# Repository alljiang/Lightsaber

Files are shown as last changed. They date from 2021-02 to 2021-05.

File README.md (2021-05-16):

# Lightsaber

EE445L Embedded Systems Lab with Dr. Valvano <br />
Final Project, 1st place in class design competition <br />
Spring 2021 <br />
Team Members: Allen Jiang, Sophia Jiang, Adeel Rehman, Sharon Chen <br />
<br />
<b>Features:</b> <br />
* Circuit Board
  * Compact 4-Layer design (Board dimensions: 1.94" x 0.90")
  * TM4C Microcontroller
  * 12-bit DAC and audio amplifier output
  * MPU-6500 IMU
  * ESP-01S Wifi Module
  * Power initiated by button and latched on by MCU - allows for zero vampire power
  * USB-C Battery Charging
  * Onboard battery protection (overvoltage, undervoltage, short)
* Firmware
  * Neopixels driven by Ping-Pong uDMA
  * ESP-01S AP-mode for TCP-IP communication with Android app
  * Android app for on-the-fly color, blade effect, and audio configuration with voltage and temperature telemetry
  * Smoothswing v2 algorithm implementation
* Hardware
  * Hilt
    * Designed in Fusion 360
    * 1" aluminum core hilt
    * Holes drilled and tapped for button access, charging port access, and mounting 3D printed parts
    * Grooves cut using a milling bit on a drill press
    * 3D printed cosmetic attachments are finished through sanding, filler spray coat, and final spray paint coat
  * Blade
    * Polycarbonate tubing (1" OD, 0.125" walls)
    * 2 parallel back-to-back LED strips of 144 pixels/m WS2812B neopixels - up to 15 amps of current
    * LEDs diffused using layers of foam and cellophane. Polycarbonate tubing is sanded on the outside.
    * 3D printed blade cap using translucent filament
  * Blade connector
    * Custom designed as two 1" circular 4-layer PCBs
    * No latching components - easy and quick connect/disconnect
    * Hilt-side connector uses 19 pogo pins to contact with 3 large ring pads on blade-side connector
  * Chassis
    * Holds electronic internals together for durability and convenience
    * 3D printed PLA
    * Houses RGB button, PCB, 21700 Li-ion battery, speaker, and hilt-side blade connector
    * Blade connector mounted using screws and hot-melt insert
    * RGB button connected with ribbon cable
<br />
  <b>Video Link:</b>
<br />

(https://www.youtube.com/watch?v=Yrs18WD5HyQ)

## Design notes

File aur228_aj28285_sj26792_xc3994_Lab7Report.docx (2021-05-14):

EE 445L Lab 7 Report Deliverables

Team members: aur228, aj28285, sj26792, xc3994

Requirements Document: Lightsaber

1. Overview
  1.1. Objectives

The objectives of this project are to design, build, and test a custom embedded system. In practice, we are building a lightsaber. Our goal is to demonstrate our understanding of embedded systems design.

  1.2. Roles and Responsibilities

We are both the engineers and the clients because we are both making a lightsaber and want a lightsaber. Responsibilities will be divided based on accessibility to lab equipment and prior PCB design experience.

  1.3. Interactions with Existing Systems

Our system will interact with a NeoPixel LED strip to output lighting effects.

2. Function Description
  2.1. Functionality

We will attempt to closely resemble the functionality of a “real” lightsaber. There will be a handle for the user to grasp, and an illuminated endpiece. If the user presses the button, the lightsaber will turn on and off. Using the lightsaber’s wi-fi connection, the user will be able to configure lightsaber settings using an app, such as color and sound. Sound and lighting effects will play depending on the lightsaber’s movement.

  2.2. Performance

The system will be judged first by the Spring 2021 EE 445L class, at the end of year competition. Second, it will also be judged by our satisfaction of the project.

Other criteria include software organization and readability, the system’s response to stimuli, and ease-of-use.

  2.3. Usability

The system will be easy to use, and not require any training. There will be very few buttons on the side of the lightsaber to control lighting. Most features will use sensor data to trigger.

3. Deliverables
  3.1. Reports

The reports for Labs 7 and 11 will be written.

  3.2. Outcomes

For Lab 7, we will deliver this requirements document, a schematic of our PCB, our software, current and cost estimations, and a discussion on debugging our system.

For Lab 11, we will deliver a more detailed requirements document, a detailed PCB schematic, a ½ page report on our software architecture, and measurement data for our system.

Additionally, we will deliver a YouTube video showcasing our product.

PCB and Schematics: uploaded on GitHub

Discussion: Debugging plan

HARDWARE:

(PCB and circuit already built and soldered, everything appears to be working correctly so far)

- We have access to lab equipment including an oscilloscope, microscope, soldering equipment, and multimeters.
- Individual connections and expected voltages can be tested using the oscilloscope, multimeter, or microscope if needed.

SOFTWARE:

- JTAG connector to enable remote testing on the board.
- Lightsaber functionalities split into different modules, which will be unit tested separately before integration
- Each member will be responsible for a few modules and the team will work together to understand other modules and how they combine.
- Modules needed include (but aren’t limited to) Buttons, timers, JTAG, WIFI (ESP module), NeoPixel LED drivers, ect.
- Modules will be integrated in tiers. Associated components will be integrated together in larger modules and tested before implementing the larger modules fully in the main loop.
- During testing stage, we will use a prototype main loop with a debugging driver to run only the things we want to test.

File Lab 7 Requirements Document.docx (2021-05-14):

EE 445L Lab 11 Report Deliverables

Requirements Document: Lightsaber

1. Overview
  1.1. Objectives

The objectives of this project are to design, build, and test a custom embedded system. In practice, we are building a lightsaber, modeled from the movie Star Wars. The lightsaber should contain lighting and sound effects which are played in response to stimuli. Our goal is to demonstrate our understanding of embedded systems design, and showcase our knowledge gained in EE 445L.

  1.2. Process

The project will be developed using the TM4C microprocessor. A custom PCB will be designed, and the microcontroller and other electrical components soldered to it. A JTAG header will be used to program and debug the embedded system. A battery and charging circuit will be soldered to provide power to the device. The user will use a custom Android app to control the sound and lighting effects of the device. There will be numerous software and hardware modules, all of which will be independently tested and validated. After each module is tested, the system will be built and tested.

  1.3. Roles and Responsibilities

We are both the engineers and the clients because we are both making a lightsaber and want a lightsaber. Responsibilities will be divided based on accessibility to lab equipment and prior PCB design experience.

  1.4. Interactions with Existing Systems

Our system will interact with a NeoPixel LED strip to output lighting effects. The NeoPixel’s interface with the TM4C using direct memory access.

Our system will also interact with our custom Android application through an ESP-01 Wi-Fi module. The user will be able to use this app to select color and sound effects to be loaded onto the embedded system. The Blynk app and interface covered in class will not be used. We will instead be using the standard AT command set that ships with the ESP module to interface with it. App communication will be done using a custom TCP protocol developed by us.

2. Function Description
  2.1. Functionality

We will attempt to closely resemble the functionality of a “real” lightsaber. There will be a handle for the user to grasp, and an illuminated endpiece. If the user presses the button, the lightsaber will turn on and off. Using the lightsaber’s wi-fi connection, the user will be able to configure lightsaber settings using an app, such as color and sound. Color can be selected from the Adobe RGB color space. Sound can be selected from a pre-loaded library in the firmware. Sound and lighting effects will play depending on the lightsaber’s movement.

There will be 8 different blade effects, 2 unique sound fonts, and a special nyan cat package.

  2.2. Performance

We will be using three primary qualitative measures to assess the performance of the system. The system will be judged first by the Spring 2021 EE 445L class, at the end of year competition. Second, it will also be judged by our satisfaction of the project. Third, it will be judged by its ability to impress our course instructor and faculty advisor, Dr. Valvano.

Other secondary criteria include software organization and readability, the system’s response to stimuli, and ease-of-use.

The software will be organized in a readable, and sharable manner. Software reviewers will be able to understand the software architecture without needing a call graph. All code will adhere to the Power Up Coding Standard for C and C++.

The system will primarily respond to IMU input. The latency must be sufficiently low that the user is not able to observe it without specialized equipment.

  2.3. Usability

The system will be easy to use, and not require any special training. There will be a single button on the side of the lightsaber toggle the system on and off. The user will download an app onto their phone from the Google play store, which can be used to control the systems sound and lighting effects. Sound effects can be chosen from a list of pre-established choices. Lighting can be chosen from the Adobe RGB color scheme, featuring 16.8 million unique colors. All other features will use input from the IMU to trigger, and not require any specific user input.

3. Deliverables
  3.1. Objectives

This 2-page requirements document.

  3.2. Hardware Design

A detailed circuit diagram of the system will be uploaded to an official github repository, to be shared with the course instructor.

  3.3. Software Design

A brief description of how our software works will be delivered.

All our software will be uploaded to an official github repository, to be shared with the course instructor and teaching assistants.

  3.4. Measurement Data

Measurement data will be included as appropriate for our system. Data will describe power consumption of system and LED’s. We will also measure the duration of the Wi-Fi handler, and the smooth swing accuracy.

  3.5. Analysis and Discussion

We will not be delivering any analysis or discussion regarding our system. A YouTube video featuring our product will be submitted to the course instructor and teaching assistants as requested.

Software Design:

Individual drivers have been built for numerous low-level hardware components, including the System Timer, NeoPixel LED’s, IMU, ESP-01, the button, sound, and battery charging.

On top of these drivers, are more complex function libraries, such as WiFi and Utilities.

All the above-mentioned modules are integrated in a main file. This file handles the primary control loop and manages initialization and updates for the other modules.

Measurement Data:

Power Measurements:

Average current drawn by total PCB: ~80mA

Current drawn by neopixels: Up to 15A

Timing Measurements:

Wifi Handler Duration: 8ms

Smoothswing accuracy:

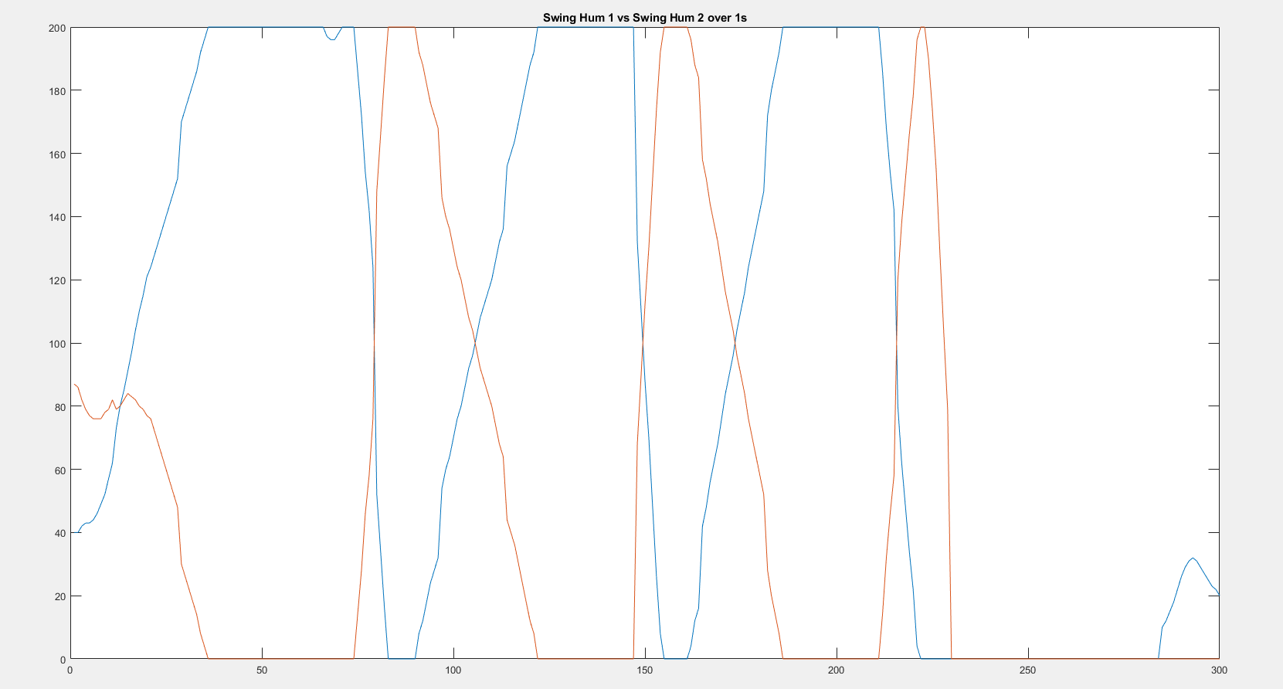
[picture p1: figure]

IMU gyro error when not moving: ~0.9 dps

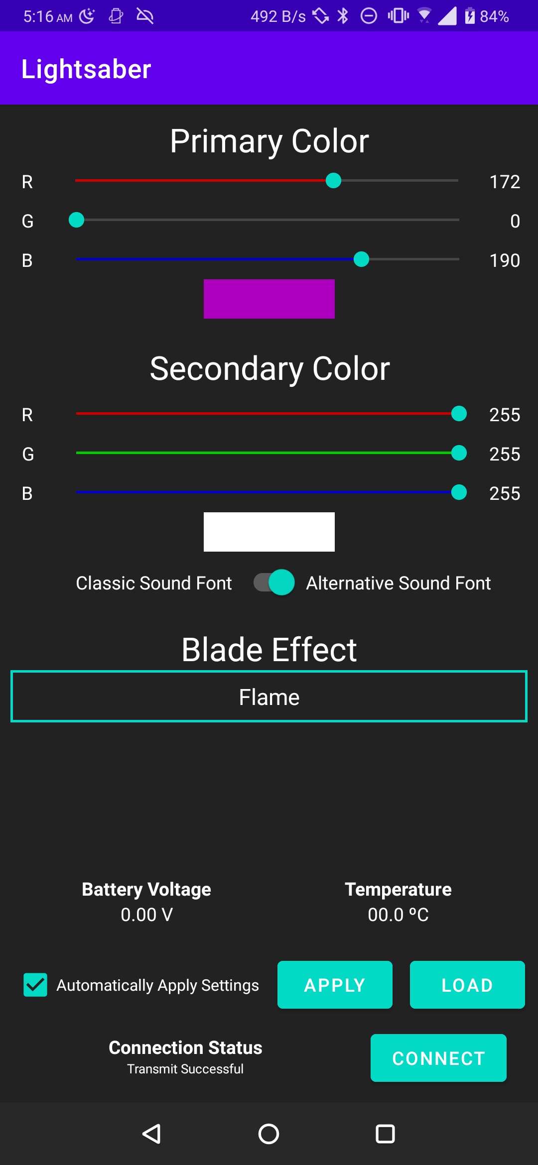
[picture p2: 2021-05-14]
Android App/screenshot2.jpg

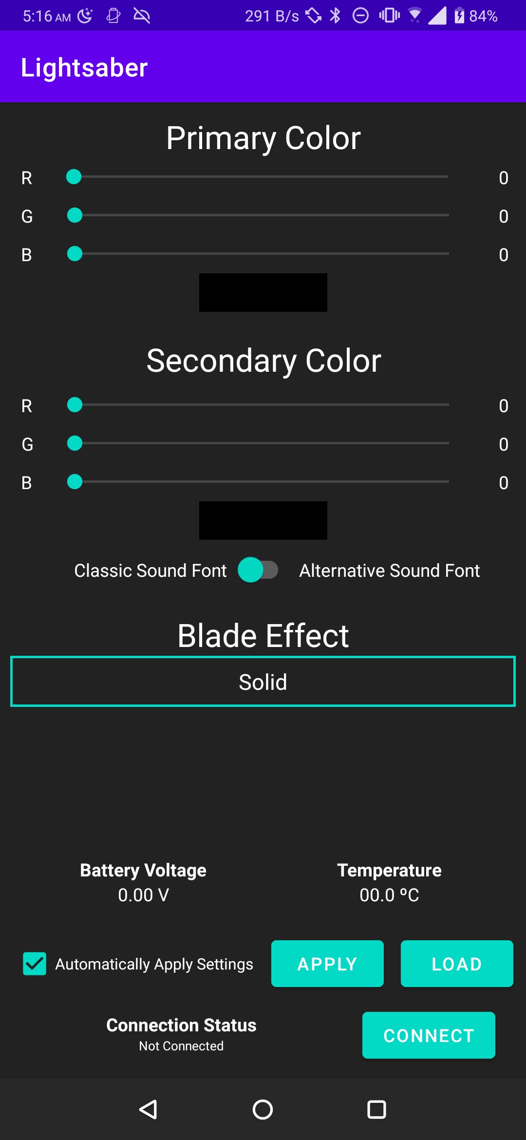
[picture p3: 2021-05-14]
Android App/screenshot1.jpg

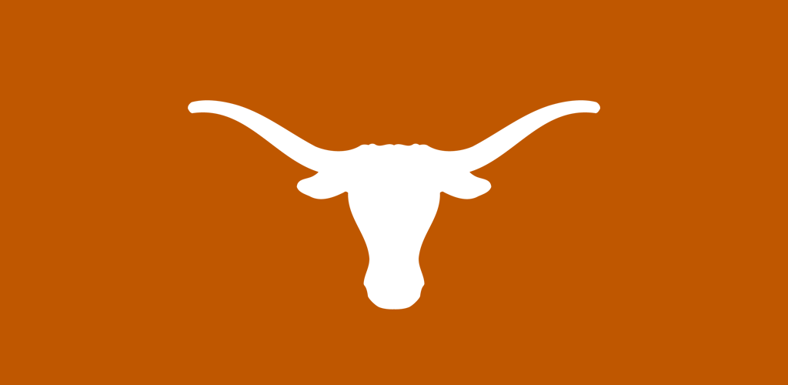
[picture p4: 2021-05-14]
Android App/feature graphic.png

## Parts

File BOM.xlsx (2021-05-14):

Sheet: Overview
Subsystem | True Cost | BOM Cost | Total Spent | Allowance | $60.00
Blade | $27.82 | $18.92 | $160.06 | Total Cost | $41.09
Hilt Electronics | $31.46 | $15.61 | $280.10 | Remaining | $18.91 | Summary:
Hilt Chassis | $8.07 | $6.56 | $95.44 |  |  | 445L BOM Cost | $41.09
 |  |  |  |  |  | Unit Cost | $67.35
 |  |  |  |  |  | Total Spent | $535.60

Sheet: Blade
Name | Description | True PPU | True Units | BOM PPU | BOM Units | True Total | BOM Total | Vendor |  |  | Purchased
Spring Pins | Contacts between blade PCB and hilt PCB, 1 data, 9 postive, 9 gnd | $12.18 | 0.13 | $0.08 | 19.00 | $1.54 | $1.54 | LCSC (https://lcsc.com/product-detail/Electronic-Accessories_Shenzhen-Kinghelm-Elec-KH-204065-DZ_C530676.html) |  |  | 150
Blade-Side PCB | Panelized | $0.00 | 1.00 | $0.00 | 1.00 | $0.00 | $0.00 | JLCPCB | True Total: | $27.82
Hilt-Side PCB | Panelized | $0.00 | 1.00 | $0.00 | 1.00 | $0.00 | $0.00 | JLCPCB | BOM Total: | $18.92
Blade-Side PCB Holder | 3D Printed | $0.00 | 1.00 | $0.00 | 1.00 | $0.00 | $0.00 | -
Hilt-Side PCB Holder | 3D Printed | $0.00 | 1.00 | $0.00 | 1.00 | $0.00 | $0.00 | - | Total Spent: | $160.06
Polycarbonate Tubing | 1" OD, 3/4" ID, Clear polycarbonate, 72" | $52.35 | 0.17 | $13.53 | 0.44 | $8.72 | $6.01 | Amazon
Cellophane | Clear Cellophane for diffusion, 32" x 100' | $7.57 | 0.33 | $7.57 | 0.33 | $2.52 | $2.52 | Amazon (https://www.amazon.com/Cellophane-Inches-Baskets-Flowers-Unfolds/dp/B07WK8PPNH)
Foam Roll | 12" wide, 50 ft, 1/16" thickness, perforated | $11.75 | 0.10 | $11.75 | 0.06 | $1.18 | $0.70 | eBay (https://www.ebay.com/itm/UBOXES-Foam-Wrap-Roll-12-Wide-x-50-ft-1-16-Thickness-Perforated-Every-12/224097161092)
Tube Cap | 3D Printed | $0.00 | 1.00 | $0.00 | 1.00 | $0.00 | $0.00 | -
Neopixel Strip | 144 Pixels per meter, 1 meters, $4 off coupon | $76.21 | 0.18 | $5.00 | 1.63 | $13.86 | $8.14 | Aliexpress (https://www.aliexpress.com/item/32838802305.html?spm=a2g0s.9042311.0.0.16ae4c4dBNLXll)
 |  | $0.00 |  | $0.00 |  | $0.00 | $0.00
 |  | $0.00 |  | $0.00 |  | $0.00 | $0.00
 |  | $0.00 |  | $0.00 |  | $0.00 | $0.00
 |  | $0.00 |  | $0.00 |  | $0.00 | $0.00
 |  | $0.00 |  | $0.00 |  | $0.00 | $0.00
 |  | $0.00 |  | $0.00 |  | $0.00 | $0.00
 |  | $0.00 |  | $0.00 |  | $0.00 | $0.00
 |  | $0.00 |  | $0.00 |  | $0.00 | $0.00
 |  | $0.00 |  | $0.00 |  | $0.00 | $0.00
 |  | $0.00 |  | $0.00 |  | $0.00 | $0.00
 |  | $0.00 |  | $0.00 |  | $0.00 | $0.00
 |  | $0.00 |  | $0.00 |  | $0.00 | $0.00
 |  | $0.00 |  | $0.00 |  | $0.00 | $0.00
 |  | $0.00 |  | $0.00 |  | $0.00 | $0.00
 |  | $0.00 |  | $0.00 |  | $0.00 | $0.00
 |  | $0.00 |  | $0.00 |  | $0.00 | $0.00
 |  | $0.00 |  | $0.00 |  | $0.00 | $0.00
 |  | $0.00 |  | $0.00 |  | $0.00 | $0.00
 |  | $0.00 |  | $0.00 |  | $0.00 | $0.00
 |  | $0.00 |  | $0.00 |  | $0.00 | $0.00
 |  | $0.00 |  | $0.00 |  | $0.00 | $0.00
 |  | $0.00 |  | $0.00 |  | $0.00 | $0.00
 |  | $0.00 |  | $0.00 |  | $0.00 | $0.00
 |  | $0.00 |  | $0.00 |  | $0.00 | $0.00
 |  | $0.00 |  | $0.00 |  | $0.00 | $0.00
 |  | $0.00 |  | $0.00 |  | $0.00 | $0.00
 |  | $0.00 |  | $0.00 |  | $0.00 | $0.00
 |  | $0.00 |  | $0.00 |  | $0.00 | $0.00
 |  | $0.00 |  | $0.00 |  | $0.00 | $0.00
 |  | $0.00 |  | $0.00 |  | $0.00 | $0.00
 |  | $0.00 |  | $0.00 |  | $0.00 | $0.00
 |  | $0.00 |  | $0.00 |  | $0.00 | $0.00
 |  | $0.00 |  | $0.00 |  | $0.00 | $0.00
 |  | $0.00 |  | $0.00 |  | $0.00 | $0.00
 |  | $0.00 |  | $0.00 |  | $0.00 | $0.00
 |  | $0.00 |  | $0.00 |  | $0.00 | $0.00
 |  | $0.00 |  | $0.00 |  | $0.00 | $0.00
 |  | $0.00 |  | $0.00 |  | $0.00 | $0.00
 |  | $0.00 |  | $0.00 |  | $0.00 | $0.00
 |  | $0.00 |  | $0.00 |  | $0.00 | $0.00
 |  | $0.00 |  | $0.00 |  | $0.00 | $0.00
 |  | $0.00 |  | $0.00 |  | $0.00 | $0.00
 |  | $0.00 |  | $0.00 |  | $0.00 | $0.00
 |  | $0.00 |  | $0.00 |  | $0.00 | $0.00
 |  | $0.00 |  | $0.00 |  | $0.00 | $0.00
 |  | $0.00 |  | $0.00 |  | $0.00 | $0.00
 |  | $0.00 |  | $0.00 |  | $0.00 | $0.00
 |  | $0.00 |  | $0.00 |  | $0.00 | $0.00
 |  | $0.00 |  | $0.00 |  | $0.00 | $0.00
 |  | $0.00 |  | $0.00 |  | $0.00 | $0.00
 |  | $0.00 |  | $0.00 |  | $0.00 | $0.00
 |  | $0.00 |  | $0.00 |  | $0.00 | $0.00
 |  | $0.00 |  | $0.00 |  | $0.00 | $0.00
 |  | $0.00 |  | $0.00 |  | $0.00 | $0.00
 |  | $0.00 |  | $0.00 |  | $0.00 | $0.00
 |  | $0.00 |  | $0.00 |  | $0.00 | $0.00
 |  | $0.00 |  | $0.00 |  | $0.00 | $0.00
 |  | $0.00 |  | $0.00 |  | $0.00 | $0.00
 |  | $0.00 |  | $0.00 |  | $0.00 | $0.00
 |  | $0.00 |  | $0.00 |  | $0.00 | $0.00
 |  | $0.00 |  | $0.00 |  | $0.00 | $0.00
 |  | $0.00 |  | $0.00 |  | $0.00 | $0.00
 |  | $0.00 |  | $0.00 |  | $0.00 | $0.00
 |  | $0.00 |  | $0.00 |  | $0.00 | $0.00
 |  | $0.00 |  | $0.00 |  | $0.00 | $0.00
 |  | $0.00 |  | $0.00 |  | $0.00 | $0.00
 |  | $0.00 |  | $0.00 |  | $0.00 | $0.00
 |  | $0.00 |  | $0.00 |  | $0.00 | $0.00
 |  | $0.00 |  | $0.00 |  | $0.00 | $0.00
 |  | $0.00 |  | $0.00 |  | $0.00 | $0.00
 |  | $0.00 |  | $0.00 |  | $0.00 | $0.00
 |  | $0.00 |  | $0.00 |  | $0.00 | $0.00
 |  | $0.00 |  | $0.00 |  | $0.00 | $0.00
 |  | $0.00 |  | $0.00 |  | $0.00 | $0.00
 |  | $0.00 |  | $0.00 |  | $0.00 | $0.00
 |  | $0.00 |  | $0.00 |  | $0.00 | $0.00
 |  | $0.00 |  | $0.00 |  | $0.00 | $0.00
 |  | $0.00 |  | $0.00 |  | $0.00 | $0.00
 |  | $0.00 |  | $0.00 |  | $0.00 | $0.00
 |  | $0.00 |  | $0.00 |  | $0.00 | $0.00
 |  | $0.00 |  | $0.00 |  | $0.00 | $0.00
 |  | $0.00 |  | $0.00 |  | $0.00 | $0.00
 |  | $0.00 |  | $0.00 |  | $0.00 | $0.00
 |  | $0.00 |  | $0.00 |  | $0.00 | $0.00
 |  | $0.00 |  | $0.00 |  | $0.00 | $0.00
 |  | $0.00 |  | $0.00 |  | $0.00 | $0.00
 |  | $0.00 |  | $0.00 |  | $0.00 | $0.00
 |  | $0.00 |  | $0.00 |  | $0.00 | $0.00
 |  | $0.00 |  | $0.00 |  | $0.00 | $0.00

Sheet: Hilt Electronics
Name | Description | True PPU | True Units | BOM PPU | BOM Units | True Total | BOM Total | Vendor |  |  | Purchased
Button | 16mm RGB Momentary Anti-Vandal Button, 3V | $30.00 | 0.1 | $1.87 | 1.00 | $3.00 | $1.87 | Aliexpress (https://www.aliexpress.com/item/4000215749571.html?spm=a2g0s.9042311.0.0.70084c4dVVgsTV) |  |  | 10
Battery | Molicel 21700 P42A 4.2Ah 45A Li-ion Battery (Black Friday Sale), True has S&H | $53.90 | 0.1 | $4.49 | 1.00 | $5.39 | $4.49 | 18650 Battery Store (https://www.18650batterystore.com/collections/21700-batteries/products/molicel-p42a) | True Total: | $31.46 | 10
Button IDC Connector | #C541864, PZ200V-12-06P, 2x3 0.1mm IDC, Pin header | $0.45 | 0.05 | $0.02 | 1.00 | $0.02 | $0.02 | LCSC (https://lcsc.com/product-detail/Pin-Header-Female-Header_XFCN-PZ200V-12-06P_C541864.html) | BOM Total: | $15.61 | 20
Button IDC Connector (Plug) | #C464601, 89361-706LF, 2x3 0.1mm IDC | $5.60 | 0.1 | $0.56 | 1.00 | $0.56 | $0.56 | LCSC (https://lcsc.com/product-detail/IDC-Connectors_Amphenol-ICC-89361-706LF_C464601.html) |  |  | 10
3.3V LDO | LD39200PU33R, 250mV @ 2A, 2000mA max, 6V max | $6.02 | 0.1 | $0.60 | 1.00 | $0.60 | $0.60 | LCSC (https://lcsc.com/product-detail/Dropout-Regulators-LDO_STMicroelectronics_LD39200PU33R_STMicroelectronics-LD39200PU33R_C222192.html) | Total Spent: | $280.10 | 10
Crystal Oscillator | NX3225GB, 16MHz, matches Y2 on TM4C Launchpad | $3.21 | 0.1 | $0.32 | 1.00 | $0.32 | $0.32 | LCSC (https://lcsc.com/product-detail/SMD-Crystal-Resonators_NDK-NX3225GB-16-000MHZ-STD-CRA-2_C528996.html) |  |  | 10
Schottky Diode | PMEG3050EP,115 30V 5A, 360mV @ 5A, SOD128 | $1.81 | 0.1 | $0.18 | 1.00 | $0.18 | $0.18 | LCSC (https://lcsc.com/product-detail/Schottky-Barrier-Diodes-SBD_Nexperia-PMEG3050EP-115_C50603.html) |  |  | 10
Battery Protection IC (30A) | XB9241A, 30A max current, 1s Li-ion | $3.18 | 0.1666666667 | $0.53 | 1.00 | $0.53 | $0.53 | LCSC (https://lcsc.com/product-detail/Battery-Protection-ICs_XySemi-XB9241A_C669692.html) |  |  | 6
Battery Protection IC (18A) | XB6206AE, 18A max current, 1s Li-ion | $1.95 | 0.1 | $0.19 | 1.00 | $0.19 | $0.19 | LCSC (https://lcsc.com/product-detail/Battery-Protection-ICs_XySemi-XB6206AE_C669682.html) |  |  | 10
Speaker | FS20MS0820-H4.3, Rated 2W, 2.5W Max, 8Ω, 0.8" Diameter | $3.42 | 0.1 | $0.34 | 1.00 | $0.34 | $0.34 | LCSC (https://lcsc.com/product-detail/Speakers_FUET-FS20MS0820-H4-3_C482325.html) |  |  | 10
Audio Amplifier | LY8006ULT, 2.5W max | $2.44 | 0.1 | $0.24 | 1.00 | $0.24 | $0.24 | LCSC (https://lcsc.com/product-detail/Audio-Power-OpAmps_Lyontek-Inc-LY8006ULT_C261883.html) |  |  | 10
Audio DAC | MCP4821 | $18.18 | 0.1 | $1.82 | 1.00 | $1.82 | $1.82 | LCSC (https://lcsc.com/product-detail/Digital-To-Analog-Converters-DACs_MICROCHIP_MCP4821-E-SN_MCP4821-E-SN_C36865.html) |  |  | 10
IMU | MPU6500 | $16.73 | 0.1 | $1.67 | 1.00 | $1.67 | $1.67 | LCSC (https://lcsc.com/product-detail/Attitude-Sensors_TDK-InvenSense_MPU6500_TDK-InvenSense-MPU6500_C50278.html) |  |  | 10
MicroSD Card Socket | TF Push | $0.59 | 0.1 | $0.06 | 1.00 | $0.06 | $0.06 | LCSC (https://lcsc.com/product-detail/Card-Sockets-Connectors_SHOU-HAN-TF-PUSH_C393941.html) |  |  | 10
Buffer | SN74LVC3G17DCUR, 3-Element, 32mA max | $1.77 | 0.1 | $0.18 | 1.00 | $0.18 | $0.18 | LCSC (https://lcsc.com/product-detail/Logic-Buffers-Drivers-Receivers-Transceivers_Texas-Instruments_SN74LVC3G17DCUR_Texas-Instruments-Texas-Instruments-SN74LVC3G17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) |  |  | 10
P Channel MOSFET | AONR21357, 30V 34A Max, Vgs=2.3V, RdsOn=7.8mΩ | $3.49 | 0.1 | $0.35 | 1.00 | $0.35 | $0.35 | LCSC (https://lcsc.com/product-detail/MOSFET_Alpha-Omega-Semicon-AOS-AONR21357_C431196.html) |  |  | 10
P Channel MOSFET | SSM3J328R,LF, 2A 6V Max, Vgs=1V, RdsOn=29.8mΩ | $1.23 | 0.05 | $0.06 | 1.00 | $0.06 | $0.06 | LCSC (https://lcsc.com/product-detail/MOSFET_TOSHIBA-SSM3J328R-LF_C396016.html) |  |  | 20
N Channel MOSFET | L2N7002SWT1G, 60V 300mA Max, Vgs=2V, RdsOn=3.2Ω | $0.82 | 0.02 | $0.02 | 1.00 | $0.02 | $0.02 | LCSC (https://lcsc.com/product-detail/MOSFET_LRC-L2N7002SWT1G_C383164.html) |  |  | 50
Battery Charger IC | BL4054B-42TPTRN, 1s | $1.03 | 0.1 | $0.10 | 1.00 | $0.10 | $0.10 | LCSC (https://lcsc.com/product-detail/PMIC-Battery-Management_BL-Shanghai-Belling-BL4054B-42TPTRN_C194062.html) |  |  | 10
Button | TS24CA, SPST 50mA 12V | $0.52 | 0.05 | $0.03 | 1.00 | $0.03 | $0.03 | LCSC (https://lcsc.com/product-detail/Tactile-Switches_SHOU-HAN-TS24CA_C393942.html) |  |  | 20
ESP-01S | Wi-Fi module using ESP8266 | $1.60 | 0.1428571429 | $0.77 | 1.00 | $0.23 | $0.77 | Taobao (https://item.taobao.com/item.htm?spm=a1z09.2.0.0.225f2e8dYBJQAO&id=612251597173&_u=p20a31gq4f1c52) |  |  | 7
Zener Diode | BZT52C4V7, 4.4V 500mW | $0.79 | 0.02 | $0.02 | 1.00 | $0.02 | $0.02 | LCSC (https://lcsc.com/product-detail/Zener-Diodes_Slkor-SLKORMICRO-Elec-BZT52C4V7_C707132.html) |  |  | 50
Zener Diode | MM1W3V3, 3.3V 1W | $0.49 | 0.05 | $0.02 | 1.00 | $0.02 | $0.02 | LCSC (https://lcsc.com/product-detail/Zener-Diodes_Shandong-Jingdao-Microelectronics-MM1W3V3_C382949.html) |  |  | 20
TM4C123GH6PMIR | Including Shipping | $61.60 | 0.1428571429 | $0.00 | 1.00 | $8.80 | $0.00 | Texas Instruments (https://www.ti.com/store/ti/en/p/product/?p=TM4C123GH6PMI7) |  |  | 7
Type C USB Connector | TYPE-C-31-M-17 | $2.51 | 0.06666666667 | $0.17 | 1.00 | $0.17 | $0.17 | LCSC (https://lcsc.com/product-detail/Others_Korean-Hroparts-Elec-TYPE-C-31-M-17_C283540.html) |  |  | 15
Male Pin Headers | 0.1", 1x5 | $0.79 | 0.02 | $0.02 | 1.00 | $0.02 | $0.02 | LCSC (https://lcsc.com/product-detail/Pin-Header-Female-Header_PINREX-210-81-05GB01_C390676.html) |  |  | 50
Female Pin Headers | 0.1", 1x10 | $0.54 | 0 | $0.05 | 0.00 | $0.00 | $0.00 | LCSC (https://lcsc.com/product-detail/Pin-Header-Female-Header_BOOMELE-Boom-Precision-Elec-2-54mm-1-10P-Straight-Female-header-Gold-plated_C35445.html) |  |  | 10
 |  | $0.00 |  | $0.00 |  | $0.00 | $0.00
 |  | $0.00 |  | $0.00 |  | $0.00 | $0.00
1000uF Capacitor | Aluminum Electrolytic SMD Capacitor, 8x10.2mm, 10V, 20%, 2000 Hrs | $1.22 | 0.06666666667 | $0.08 | 1.00 | $0.08 | $0.08 | LCSC (https://lcsc.com/product-detail/Aluminum-Electrolytic-Capacitors-SMD_ROQANG-RT1A102M0810_C280406.html) |  |  | 15
2.2uF Capacitor | MLCC capacitor, 0402, 2.2uF, rated 10V, 10% | $0.53 | 0.01 | $0.01 | 1.00 | $0.01 | $0.01 | LCSC (https://lcsc.com/product-detail/Multilayer-Ceramic-Capacitors-MLCC-SMD-SMT_Samsung-Electro-Mechanics-CL05A225KP5NSNC_C107369.html) |  |  | 100
1uF Capacitor | MLCC capacitor, 0402, 1uF, rated 16V, 10% | $0.24 | 0.02 | $0.0024 | 2.00 | $0.0048 | $0.0048 | LCSC (https://lcsc.com/product-detail/Multilayer-Ceramic-Capacitors-MLCC-SMD-SMT_SAMSUNG_CL05A105KO5NNNC_1uF-105-10-16V_C29266.html) |  |  | 100
10uF Capacitor | MLCC capacitor, 0402, 10uF, rated 10V | $1.66 | 0.06 | $0.02 | 6.00 | $0.10 | $0.10 | LCSC (https://lcsc.com/product-detail/_Taiyo-Yuden-LDK105CBJ106MVLF_C386033.html) |  |  | 100
10pF Capacitor | MLCC capacitor, 0402, 10pF, rated 50V, NP0, 5% | $0.13 | 0.02 | $0.0013 | 2.00 | $0.0026 | $0.0026 | LCSC (https://lcsc.com/product-detail/Multilayer-Ceramic-Capacitors-MLCC-SMD-SMT_10pF-100-5-50V_C106199.html) |  |  | 100
0.1uF Capacitor | MLCC capacitor, 0402, 0.1uF, rated 16V, 5% | $2.00 | 0.017 | $0.002 | 17.00 | $0.03 | $0.03 | LCSC (https://lcsc.com/product-detail/Multilayer-Ceramic-Capacitors-MLCC-SMD-SMT_Walsin-Tech-Corp-0402B104J160CT_C387940.html) |  |  | 1000
68nF Capacitor | MLCC capacitor, 0402, 68nF, rated 25V, 10% | $0.25 | 0.01 | $0.0025 | 1.00 | $0.0025 | $0.0025 | LCSC (https://lcsc.com/product-detail/Multilayer-Ceramic-Capacitors-MLCC-SMD-SMT_VIIYONG-V683K0402X5R250NBT_C610201.html) |  |  | 100
 |  | $0.00 |  | $0.00 |  | $0.00 | $0.00
 |  | $0.00 |  | $0.00 |  | $0.00 | $0.00
10kΩ Resistor | 0402, 10kΩ, 0.1W, 1% | $2.30 | 0.036 | $0.0023 | 12.00 | $0.08 | $0.03 | LCSC (https://lcsc.com/product-detail/Others_KAMAYA-RMC10K103FTH_C323692.html) |  |  | 1000
2.2kΩ Resistor | 0402, 2.2kΩ, 0.125W, 1% | $0.25 | 0.03 | $0.0025 | 1.00 | $0.01 | $0.0025 | LCSC (https://lcsc.com/product-detail/Chip-Resistor-Surface-Mount_YAGEO-RC0402FR-7W2K2L_C606171.html) |  |  | 100
470Ω Resistor | 0402, 470Ω, 0.125W, 1% | $0.26 | 0.06 | $0.0026 | 2.00 | $0.02 | $0.01 | LCSC (https://lcsc.com/product-detail/Chip-Resistor-Surface-Mount_YAGEO-RC0402FR-7W470RL_C606172.html) |  |  | 100
100Ω Resistor | 0402, 100Ω, 0.1W, 1% | $0.32 | 0.03 | $0.0032 | 1.00 | $0.01 | $0.0032 | LCSC (https://lcsc.com/product-detail/Others_KAMAYA-RMC10K101FTH_C323694.html) |  |  | 100
475kΩ Resistor | 0402, 475kΩ, 0.16W, 1% | $0.07 | 0.03 | $0.0007 | 1.00 | $0.0021 | $0.0007 | LCSC (https://lcsc.com/product-detail/Chip-Resistor-Surface-Mount_YAGEO-RC0402FR-07475KL_C477742.html) |  |  | 100
1Ω Resistor | 0402, 1Ω, 0.1W, 1% | $0.24 | 0 | $0.00237 | 0.00 | $0.00 | $0.00 | LCSC (https://lcsc.com/product-detail/Chip-Resistor-Surface-Mount_1R-1R00-1_C159962.html) |  |  | 100
1kΩ Resistor | 0402, 1kΩ, 1/16W, 1% | $0.06 | 0.12 | $0.0006 | 4.00 | $0.01 | $0.0024 | LCSC (https://lcsc.com/product-detail/Chip-Resistor-Surface-Mount_FH-Guangdong-Fenghua-Advanced-Tech-RC-02W1001FT_C226166.html) |  |  | 100
806kΩ Resistor | 0402, 806kΩ, 1/16W, 1% | $0.06 | 0.03 | $0.0006 | 1.00 | $0.0018 | $0.0006 | LCSC (https://lcsc.com/product-detail/Chip-Resistor-Surface-Mount_806KR-8063-1_C103164.html) |  |  | 100
1.24kΩ Resistor | 0402, 1.24kΩ, 1/16W, 1% | $0.07 | 0.03 | $0.0007 | 1.00 | $0.0021 | $0.0007 | LCSC (https://lcsc.com/product-detail/Chip-Resistor-Surface-Mount_UNI-ROYAL-Uniroyal-Elec-0402WGF1241TCE_C25864.html) |  |  | 100
 |  | $0.00 |  | $0.00 |  | $0.00 | $0.00
LCSC Shipping |  | $23.97 | 0.1666666667 | $0.00 |  | $4.00 | $0.00
PCB | 10pcs, 4 layer, < 50mm x 50mm, True includes S&H | $21.80 | 0.1 | $0.70 | 1.00 | $2.18 | $0.70 | JLCPCB
 |  | $0.00 |  | $0.00 |  | $0.00 | $0.00
 |  | $0.00 |  | $0.00 |  | $0.00 | $0.00
 |  | $0.00 |  | $0.00 |  | $0.00 | $0.00
 |  | $0.00 |  | $0.00 |  | $0.00 | $0.00
 |  | $0.00 |  | $0.00 |  | $0.00 | $0.00
 |  | $0.00 |  | $0.00 |  | $0.00 | $0.00
 |  | $0.00 |  | $0.00 |  | $0.00 | $0.00
 |  | $0.00 |  | $0.00 |  | $0.00 | $0.00
 |  | $0.00 |  | $0.00 |  | $0.00 | $0.00
 |  | $0.00 |  | $0.00 |  | $0.00 | $0.00
 |  | $0.00 |  | $0.00 |  | $0.00 | $0.00
 |  | $0.00 |  | $0.00 |  | $0.00 | $0.00
 |  | $0.00 |  | $0.00 |  | $0.00 | $0.00
 |  | $0.00 |  | $0.00 |  | $0.00 | $0.00
 |  | $0.00 |  | $0.00 |  | $0.00 | $0.00
 |  | $0.00 |  | $0.00 |  | $0.00 | $0.00
 |  | $0.00 |  | $0.00 |  | $0.00 | $0.00
 |  | $0.00 |  | $0.00 |  | $0.00 | $0.00
 |  | $0.00 |  | $0.00 |  | $0.00 | $0.00
 |  | $0.00 |  | $0.00 |  | $0.00 | $0.00
 |  | $0.00 |  | $0.00 |  | $0.00 | $0.00
 |  | $0.00 |  | $0.00 |  | $0.00 | $0.00
 |  | $0.00 |  | $0.00 |  | $0.00 | $0.00
 |  | $0.00 |  | $0.00 |  | $0.00 | $0.00
 |  | $0.00 |  | $0.00 |  | $0.00 | $0.00
 |  | $0.00 |  | $0.00 |  | $0.00 | $0.00
 |  | $0.00 |  | $0.00 |  | $0.00 | $0.00
 |  | $0.00 |  | $0.00 |  | $0.00 | $0.00
 |  | $0.00 |  | $0.00 |  | $0.00 | $0.00
 |  | $0.00 |  | $0.00 |  | $0.00 | $0.00
 |  | $0.00 |  | $0.00 |  | $0.00 | $0.00
 |  | $0.00 |  | $0.00 |  | $0.00 | $0.00
 |  | $0.00 |  | $0.00 |  | $0.00 | $0.00
 |  | $0.00 |  | $0.00 |  | $0.00 | $0.00
 |  | $0.00 |  | $0.00 |  | $0.00 | $0.00
 |  | $0.00 |  | $0.00 |  | $0.00 | $0.00
 |  | $0.00 |  | $0.00 |  | $0.00 | $0.00
 |  | $0.00 |  | $0.00 |  | $0.00 | $0.00
 |  | $0.00 |  | $0.00 |  | $0.00 | $0.00
 |  | $0.00 |  | $0.00 |  | $0.00 | $0.00
 |  | $0.00 |  | $0.00 |  | $0.00 | $0.00
 |  | $0.00 |  | $0.00 |  | $0.00 | $0.00
 |  | $0.00 |  | $0.00 |  | $0.00 | $0.00
 |  | $0.00 |  | $0.00 |  | $0.00 | $0.00
 |  | $0.00 |  | $0.00 |  | $0.00 | $0.00
 |  | $0.00 |  | $0.00 |  | $0.00 | $0.00
 |  | $0.00 |  | $0.00 |  | $0.00 | $0.00
 |  | $0.00 |  | $0.00 |  | $0.00 | $0.00
 |  | $0.00 |  | $0.00 |  | $0.00 | $0.00
 |  | $0.00 |  | $0.00 |  | $0.00 | $0.00
 |  | $0.00 |  | $0.00 |  | $0.00 | $0.00
 |  | $0.00 |  | $0.00 |  | $0.00 | $0.00
 |  | $0.00 |  | $0.00 |  | $0.00 | $0.00
 |  | $0.00 |  | $0.00 |  | $0.00 | $0.00
 |  | $0.00 |  | $0.00 |  | $0.00 | $0.00
 |  | $0.00 |  | $0.00 |  | $0.00 | $0.00
 |  | $0.00 |  | $0.00 |  | $0.00 | $0.00
 |  | $0.00 |  | $0.00 |  | $0.00 | $0.00
 |  | $0.00 |  | $0.00 |  | $0.00 | $0.00
 |  | $0.00 |  | $0.00 |  | $0.00 | $0.00

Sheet: Hilt Chassis
Name | Description | True PPU | True Units | BOM PPU | BOM Units | True Total | BOM Total | Vendor
1ft Aluminum Pipe | Bought as 8ft and cut, 1" ID, 0.113" Thick | $31.91 | 0.125 | $31.91 | 0.12 | $3.99 | $3.99 | Home Depot (https://www.homedepot.com/p/8-ft-1-in-L-IPS-Sch-40-Aluminum-Pipe-50-A100ID-8/204487850)
Hilt Coupler | 3" Aluminum tube, bought as 4ft, 0.75" OD, 0.113" Thick | $12.07 | 0.125 | $12.07 | 0.00 | $1.51 | $0.00 | Home Depot (https://www.homedepot.com/p/4-ft-3-4-in-L-IPS-Sch-40-Aluminum-Pipe-50-A034ID-4/204484971) | True Total: | $8.07
Spray Paint | Flat Black, Glossy Black, Titanium Silver, Gloss Aluminum, Gray Filler/Primer | $51.46 | 0.05 | $51.46 | 0.05 | $2.57 | $2.57 | Home Depot (https://www.homedepot.com/p/Rust-Oleum-Automotive-11-oz-Gray-Filler-Primer-Spray-6-Pack-249279/205146490) | BOM Total: | $6.56
 |  | $0.00 |  | $0.00 |  | $0.00 | $0.00
 |  | $0.00 |  | $0.00 |  | $0.00 | $0.00 |  | Total Spent: | $95.44
 |  | $0.00 |  | $0.00 |  | $0.00 | $0.00
 |  | $0.00 |  | $0.00 |  | $0.00 | $0.00
 |  | $0.00 |  | $0.00 |  | $0.00 | $0.00
 |  | $0.00 |  | $0.00 |  | $0.00 | $0.00
 |  | $0.00 |  | $0.00 |  | $0.00 | $0.00
 |  | $0.00 |  | $0.00 |  | $0.00 | $0.00
 |  | $0.00 |  | $0.00 |  | $0.00 | $0.00
 |  | $0.00 |  | $0.00 |  | $0.00 | $0.00
 |  | $0.00 |  | $0.00 |  | $0.00 | $0.00
 |  | $0.00 |  | $0.00 |  | $0.00 | $0.00
 |  | $0.00 |  | $0.00 |  | $0.00 | $0.00
 |  | $0.00 |  | $0.00 |  | $0.00 | $0.00
 |  | $0.00 |  | $0.00 |  | $0.00 | $0.00
 |  | $0.00 |  | $0.00 |  | $0.00 | $0.00
 |  | $0.00 |  | $0.00 |  | $0.00 | $0.00
 |  | $0.00 |  | $0.00 |  | $0.00 | $0.00
 |  | $0.00 |  | $0.00 |  | $0.00 | $0.00
 |  | $0.00 |  | $0.00 |  | $0.00 | $0.00
 |  | $0.00 |  | $0.00 |  | $0.00 | $0.00
 |  | $0.00 |  | $0.00 |  | $0.00 | $0.00
 |  | $0.00 |  | $0.00 |  | $0.00 | $0.00
 |  | $0.00 |  | $0.00 |  | $0.00 | $0.00
 |  | $0.00 |  | $0.00 |  | $0.00 | $0.00
 |  | $0.00 |  | $0.00 |  | $0.00 | $0.00
 |  | $0.00 |  | $0.00 |  | $0.00 | $0.00
 |  | $0.00 |  | $0.00 |  | $0.00 | $0.00
 |  | $0.00 |  | $0.00 |  | $0.00 | $0.00
 |  | $0.00 |  | $0.00 |  | $0.00 | $0.00
 |  | $0.00 |  | $0.00 |  | $0.00 | $0.00
 |  | $0.00 |  | $0.00 |  | $0.00 | $0.00
 |  | $0.00 |  | $0.00 |  | $0.00 | $0.00
 |  | $0.00 |  | $0.00 |  | $0.00 | $0.00
 |  | $0.00 |  | $0.00 |  | $0.00 | $0.00
 |  | $0.00 |  | $0.00 |  | $0.00 | $0.00
 |  | $0.00 |  | $0.00 |  | $0.00 | $0.00
 |  | $0.00 |  | $0.00 |  | $0.00 | $0.00
 |  | $0.00 |  | $0.00 |  | $0.00 | $0.00
 |  | $0.00 |  | $0.00 |  | $0.00 | $0.00
 |  | $0.00 |  | $0.00 |  | $0.00 | $0.00
 |  | $0.00 |  | $0.00 |  | $0.00 | $0.00
 |  | $0.00 |  | $0.00 |  | $0.00 | $0.00
 |  | $0.00 |  | $0.00 |  | $0.00 | $0.00
 |  | $0.00 |  | $0.00 |  | $0.00 | $0.00
 |  | $0.00 |  | $0.00 |  | $0.00 | $0.00
 |  | $0.00 |  | $0.00 |  | $0.00 | $0.00
 |  | $0.00 |  | $0.00 |  | $0.00 | $0.00
 |  | $0.00 |  | $0.00 |  | $0.00 | $0.00
 |  | $0.00 |  | $0.00 |  | $0.00 | $0.00
 |  | $0.00 |  | $0.00 |  | $0.00 | $0.00
 |  | $0.00 |  | $0.00 |  | $0.00 | $0.00
 |  | $0.00 |  | $0.00 |  | $0.00 | $0.00
 |  | $0.00 |  | $0.00 |  | $0.00 | $0.00
 |  | $0.00 |  | $0.00 |  | $0.00 | $0.00
 |  | $0.00 |  | $0.00 |  | $0.00 | $0.00
 |  | $0.00 |  | $0.00 |  | $0.00 | $0.00
 |  | $0.00 |  | $0.00 |  | $0.00 | $0.00
 |  | $0.00 |  | $0.00 |  | $0.00 | $0.00
 |  | $0.00 |  | $0.00 |  | $0.00 | $0.00
 |  | $0.00 |  | $0.00 |  | $0.00 | $0.00
 |  | $0.00 |  | $0.00 |  | $0.00 | $0.00
 |  | $0.00 |  | $0.00 |  | $0.00 | $0.00
 |  | $0.00 |  | $0.00 |  | $0.00 | $0.00
 |  | $0.00 |  | $0.00 |  | $0.00 | $0.00
 |  | $0.00 |  | $0.00 |  | $0.00 | $0.00
 |  | $0.00 |  | $0.00 |  | $0.00 | $0.00
 |  | $0.00 |  | $0.00 |  | $0.00 | $0.00
 |  | $0.00 |  | $0.00 |  | $0.00 | $0.00
 |  | $0.00 |  | $0.00 |  | $0.00 | $0.00
 |  | $0.00 |  | $0.00 |  | $0.00 | $0.00
 |  | $0.00 |  | $0.00 |  | $0.00 | $0.00
 |  | $0.00 |  | $0.00 |  | $0.00 | $0.00
 |  | $0.00 |  | $0.00 |  | $0.00 | $0.00
 |  | $0.00 |  | $0.00 |  | $0.00 | $0.00
 |  | $0.00 |  | $0.00 |  | $0.00 | $0.00
 |  | $0.00 |  | $0.00 |  | $0.00 | $0.00
 |  | $0.00 |  | $0.00 |  | $0.00 | $0.00
 |  | $0.00 |  | $0.00 |  | $0.00 | $0.00
 |  | $0.00 |  | $0.00 |  | $0.00 | $0.00
 |  | $0.00 |  | $0.00 |  | $0.00 | $0.00
 |  | $0.00 |  | $0.00 |  | $0.00 | $0.00
 |  | $0.00 |  | $0.00 |  | $0.00 | $0.00
 |  | $0.00 |  | $0.00 |  | $0.00 | $0.00
 |  | $0.00 |  | $0.00 |  | $0.00 | $0.00
 |  | $0.00 |  | $0.00 |  | $0.00 | $0.00
 |  | $0.00 |  | $0.00 |  | $0.00 | $0.00
 |  | $0.00 |  | $0.00 |  | $0.00 | $0.00
 |  | $0.00 |  | $0.00 |  | $0.00 | $0.00
 |  | $0.00 |  | $0.00 |  | $0.00 | $0.00
 |  | $0.00 |  | $0.00 |  | $0.00 | $0.00
 |  | $0.00 |  | $0.00 |  | $0.00 | $0.00
 |  | $0.00 |  | $0.00 |  | $0.00 | $0.00
 |  | $0.00 |  | $0.00 |  | $0.00 | $0.00
 |  | $0.00 |  | $0.00 |  | $0.00 | $0.00
 |  | $0.00 |  | $0.00 |  | $0.00 | $0.00
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

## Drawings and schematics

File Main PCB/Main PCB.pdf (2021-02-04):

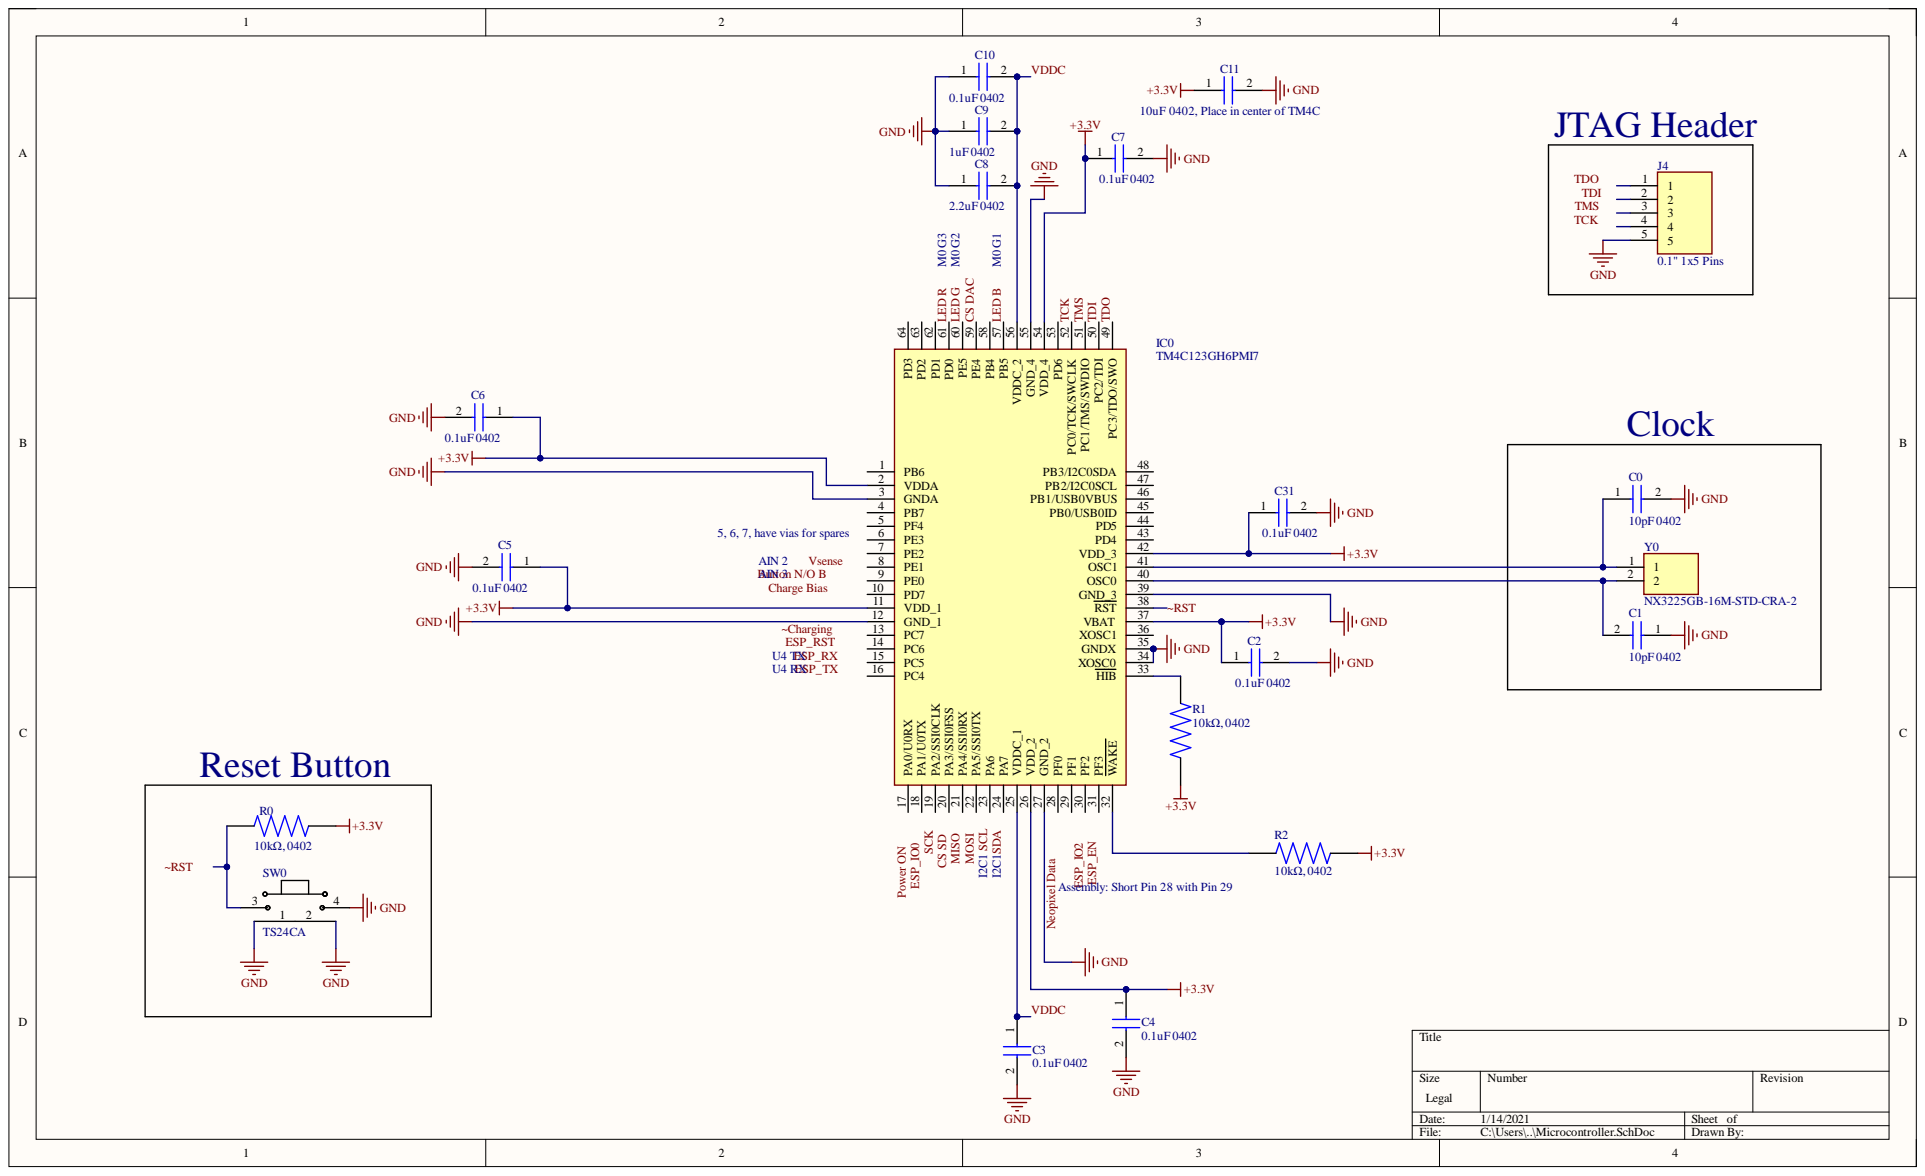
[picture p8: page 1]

10uF 0402, Place in center of TM4C

5, 6, 7, have vias for spares

Assembly: Short Pin 28 with Pin 29

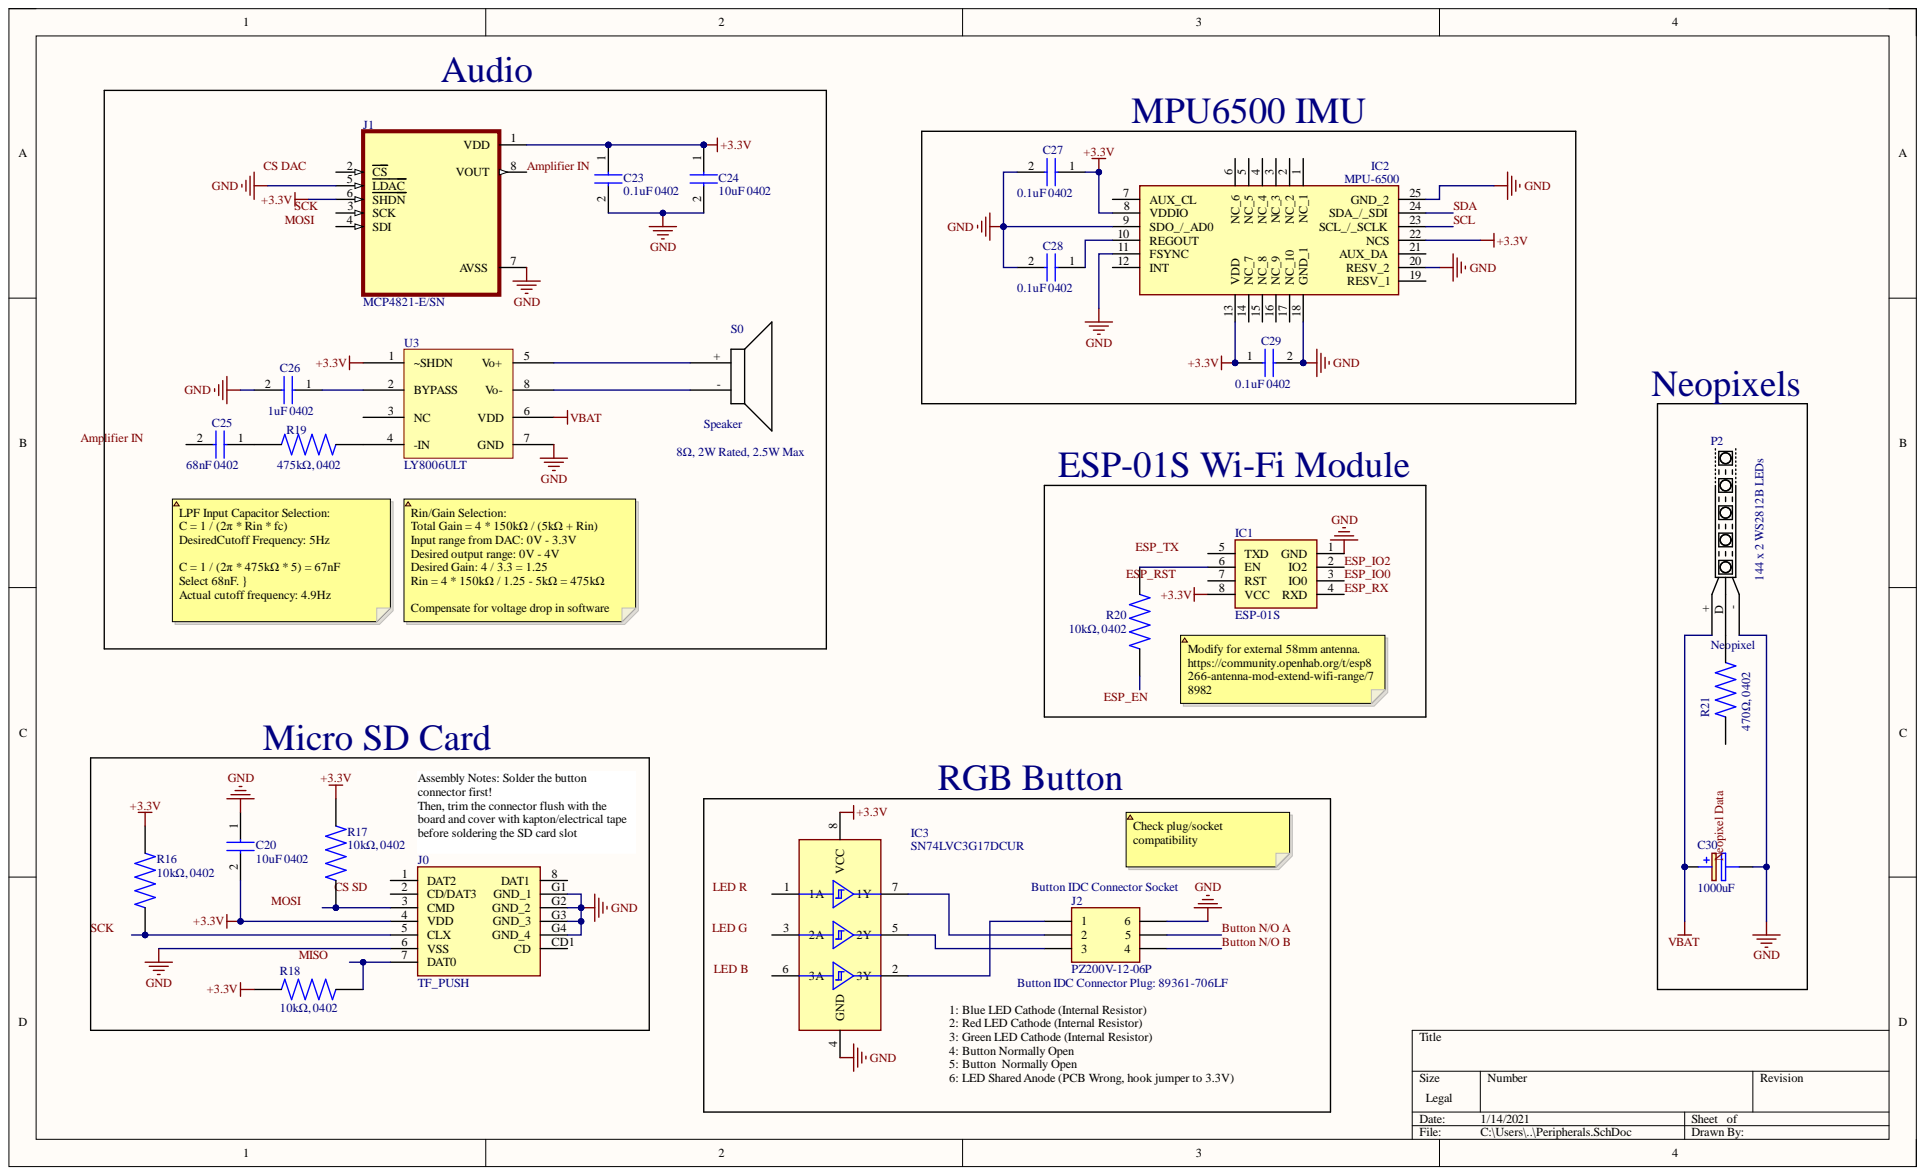
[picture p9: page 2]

ESP-01S Wi-Fi Module

LPF Input Capacitor Selection:
C = 1 / (2π * Rin * fc)
DesiredCutoff Frequency: 5Hz

Rin/Gain Selection:
Total Gain = 4 * 150kΩ / (5kΩ + Rin)
Input range from DAC: 0V - 3.3V
Desired output range: 0V - 4V
Desired Gain: 4 / 3.3 = 1.25
Rin = 4 * 150kΩ / 1.25 - 5kΩ = 475kΩ

Compensate for voltage drop in software

Modify for external 58mm antenna.
https://community.openhab.org/t/esp8
266-antenna-mod-extend-wifi-range/7

Assembly Notes: Solder the button
connector first!
Then, trim the connector flush with the
board and cover with kapton/electrical tape
before soldering the SD card slot

Button IDC Connector Socket

Button IDC Connector Plug: 89361-706LF

1: Blue LED Cathode (Internal Resistor)
2: Red LED Cathode (Internal Resistor)
3: Green LED Cathode (Internal Resistor)
4: Button Normally Open
5: Button Normally Open
6: LED Shared Anode (PCB Wrong, hook jumper to 3.3V)

Size Legal | Number | Revision

Date: 1/14/2021 | Sheet of
File: C:\Users\..\Peripherals.SchDoc | Drawn By:

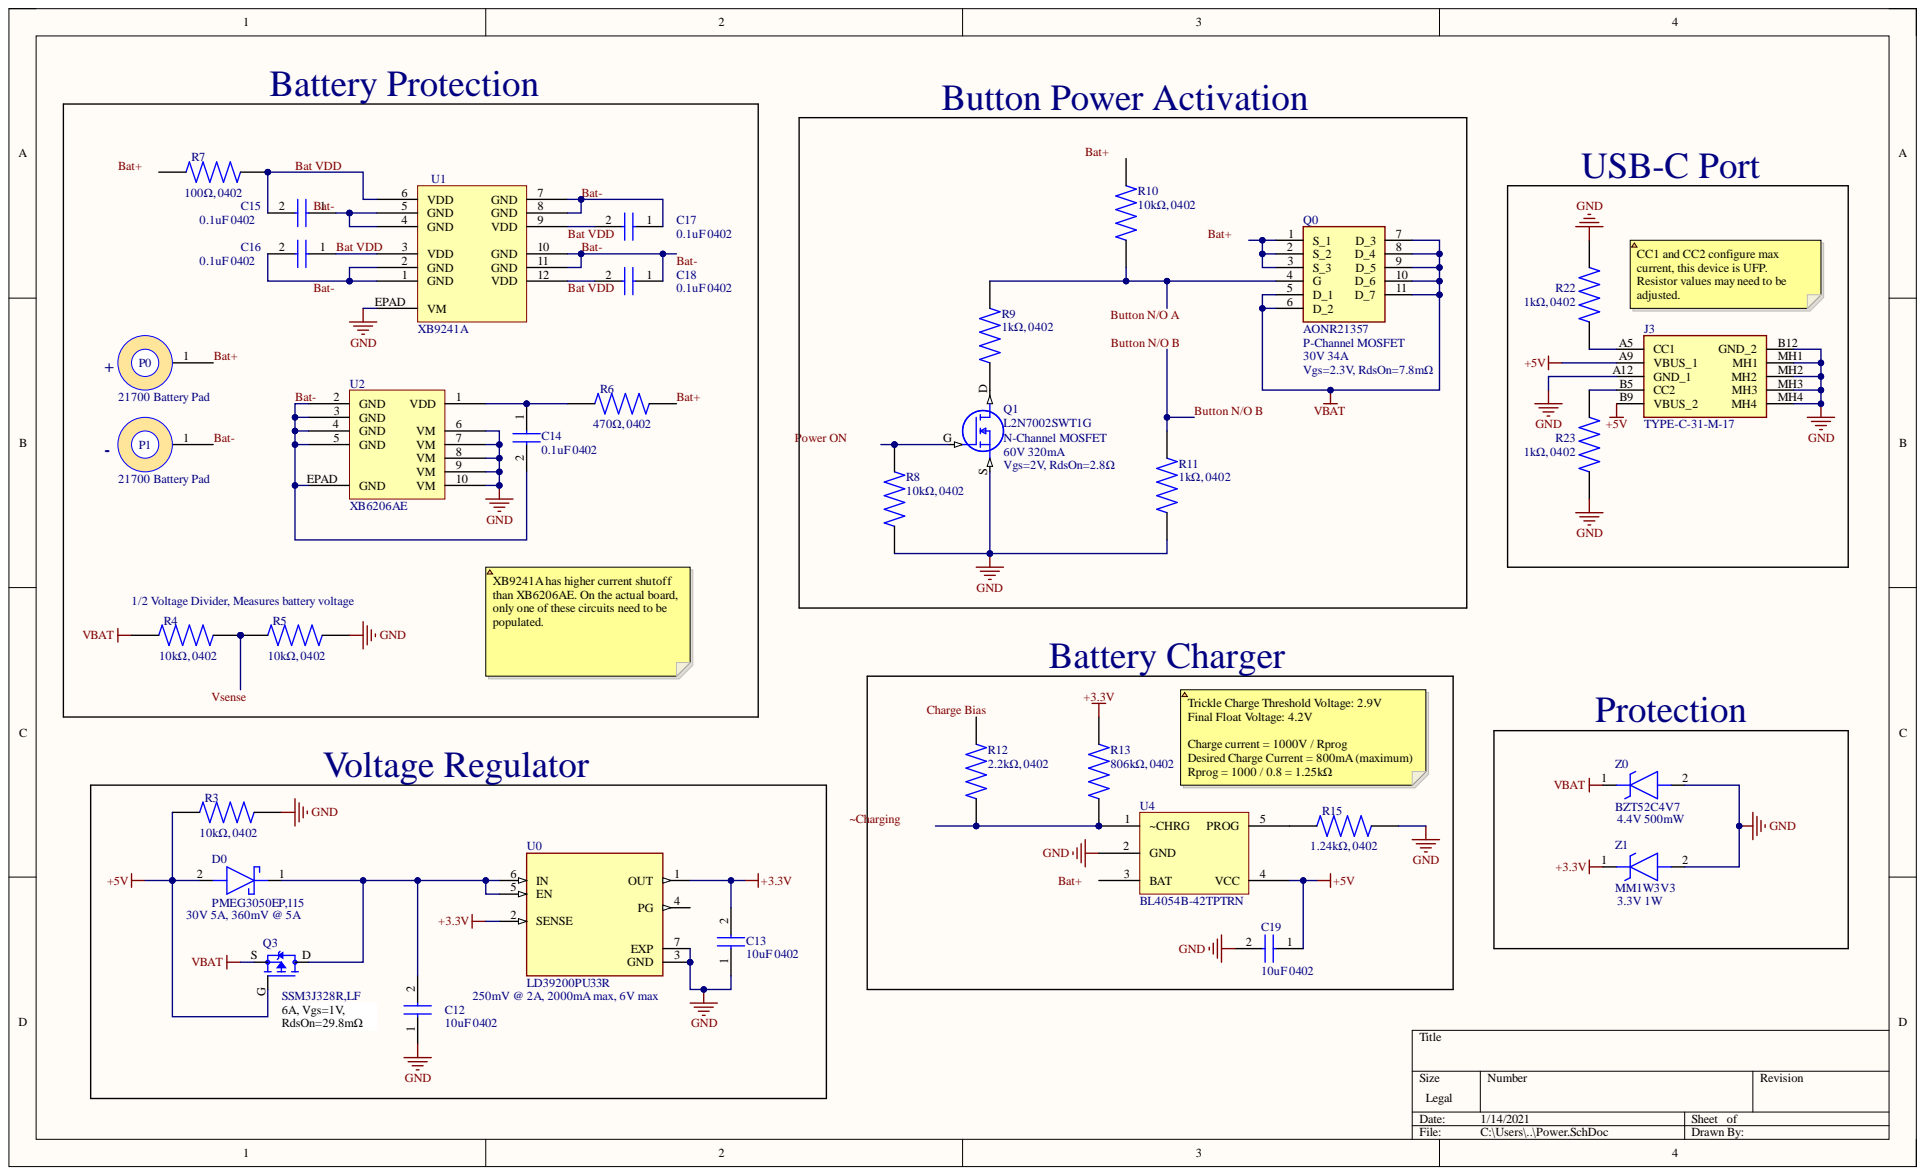
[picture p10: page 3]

Bat+ | R10 10kΩ, 0402 Q0

GND 4 GND 5

CC1 and CC2 configure max
current, this device is UFP.
Resistor values may need to be
adjusted.

XB9241Ahas higher current shutoff
than XB6206AE. On the actual board,
only one of these circuits need to be
populated.

1/2 Voltage Divider, Measures battery voltage

Trickle Charge Threshold Voltage: 2.9V
Final Float Voltage: 4.2V

Charge current = 1000V / Rprog
Desired Charge Current = 800mA(maximum)
Rprog = 1000 / 0.8 = 1.25kΩ

Date: 1/14/2021 | Sheet of
File: C:\Users\..\Power.SchDoc | Drawn By:

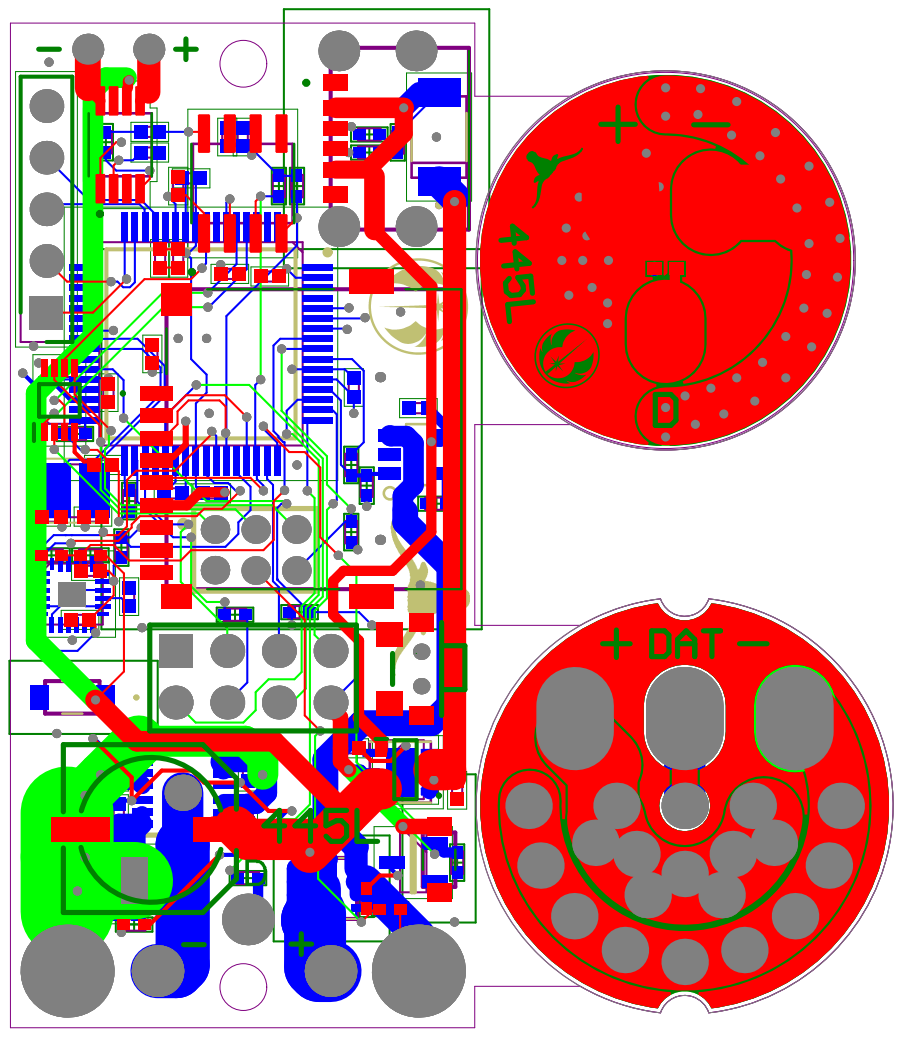
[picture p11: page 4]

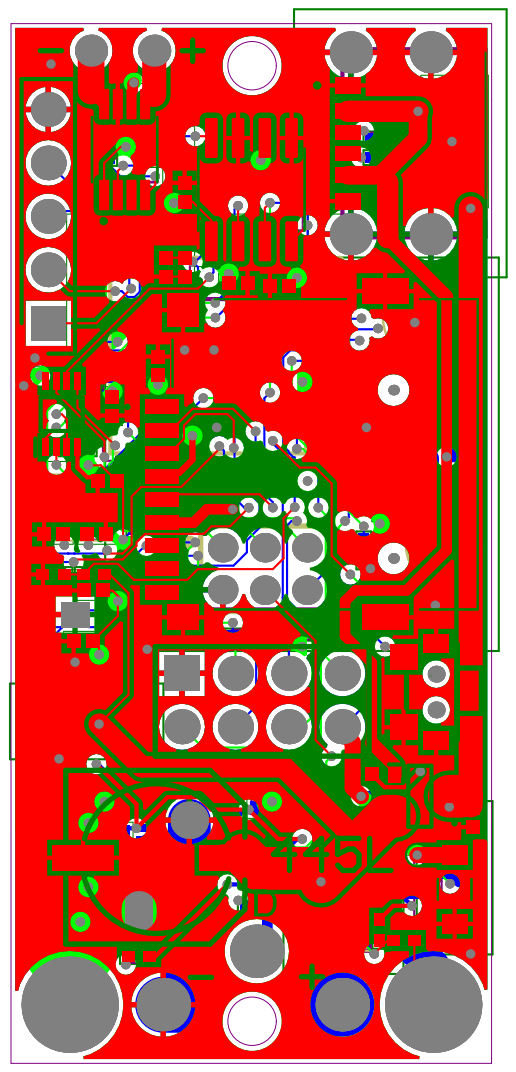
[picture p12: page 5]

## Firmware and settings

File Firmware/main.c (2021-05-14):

#include <PLL.h>
#include <stdint.h>
#include <stdbool.h>
#include "inc/hw_ints.h"
#include "inc/hw_memmap.h"
#include "inc/hw_pwm.h"
#include "inc/hw_sysctl.h"
#include "inc/hw_ssi.h"
#include "inc/hw_types.h"
#include "inc/hw_gpio.h"
#include "driverlib/adc.h"
#include "driverlib/debug.h"
#include "driverlib/interrupt.h"
#include "driverlib/sysctl.h"
#include "driverlib/pin_map.h"
#include "driverlib/pwm.h"
#include "driverlib/gpio.h"
#include "driverlib/rom.h"
#include "driverlib/udma.h"
#include "driverlib/ssi.h"
#include "driverlib/rom_map.h"
#include "driverlib/systick.h"
#include "driverlib/timer.h"

#include "Audio.h"
#include "Button.h"
#include "EEPROM.h"
#include "ESP.h"
#include "IMU.h"
#include "Neopixel.h"
#include "Power.h"
#include "Wifi.h"
#include "Utils.h"

#include "pinConfig.h"
#include "OTFConfig.h"
#include "TimeHandler.h"

extern int Neopixel_Update_Flag;

uint32_t batteryVoltage = 0;

//  OTF Config saved here
volatile uint8_t primaryR;
volatile uint8_t primaryG;
volatile uint8_t primaryB;
volatile uint8_t secondaryR;
volatile uint8_t secondaryG;
volatile uint8_t secondaryB;
volatile uint8_t fontIndex;
volatile uint8_t bladeEffectIndex;

//  1000 Hz Handler
void Timer0IntHandler(void) {
    TimerIntClear(TIMER0_BASE, TIMER_TIMA_TIMEOUT);

    millisHandler();
}

void SysTickIntHandler(void) {
}

void setupPins() {

    // Unlock PF0
    ROM_SysCtlPeripheralEnable(SYSCTL_PERIPH_GPIOF);
    HWREG(GPIO_PORTF_BASE+GPIO_O_LOCK) = GPIO_LOCK_KEY;
    HWREG(GPIO_PORTF_BASE+GPIO_O_CR) |= GPIO_PIN_0;

    // Enable Peripherals
    SysCtlPeripheralEnable(SYSCTL_PERIPH_GPIOA);
    SysCtlPeripheralEnable(SYSCTL_PERIPH_GPIOB);
    SysCtlPeripheralEnable(SYSCTL_PERIPH_GPIOC);
    SysCtlPeripheralEnable(SYSCTL_PERIPH_GPIOD);
    SysCtlPeripheralEnable(SYSCTL_PERIPH_GPIOE);
    SysCtlPeripheralEnable(SYSCTL_PERIPH_GPIOF);
    while(!SysCtlPeripheralReady(SYSCTL_PERIPH_GPIOF)) {}
}

void setupInterrupts() {
    IntMasterDisable();
    //  Systick
//    SysTickPeriodSet(10);
//    SysTickPeriodSet(SysCtlClockGet() / 2);
//    SysTickIntEnable();
//    SysTickEnable();

    //  Timer 0
    SysCtlPeripheralEnable(SYSCTL_PERIPH_TIMER0);

    TimerConfigure(TIMER0_BASE, TIMER_CFG_PERIODIC);
    TimerLoadSet(TIMER0_BASE, TIMER_A, SysCtlClockGet() / 1000); // 1000 Hz

    IntEnable(INT_TIMER0A);
    TimerIntEnable(TIMER0_BASE, TIMER_TIMA_TIMEOUT);

    TimerEnable(TIMER0_BASE, TIMER_A);

    IntMasterEnable();
}

uint32_t last_ButtonLEDHandler = 0;
uint32_t last_VoltageHandler = 0;
uint32_t last_NeopixelHandler = 0;
uint32_t last_IMUHandler = 0;
uint32_t last_EEPROMHandler = 0;
uint32_t last_WifiHandler = 0;
uint32_t last_WifiInfoHandler = 0;
bool connectedToPhone = false;

void handlerLoop() {
    long time = millis();

    Neopixel_handler();

    if(time - last_ButtonLEDHandler >= 10) {
        last_ButtonLEDHandler = time;
        Button_Handler();
    }

    if(time - last_VoltageHandler >= 1000) {
        last_VoltageHandler = time;

//        batteryVoltage = Power_getBatteryVoltage(); //  scaled by 1000
//        if(x < 3400) {
//            Power_latchOff();
//        }
    }

    if(time - last_IMUHandler >= 2) {
        last_IMUHandler = time;
        IMU_update();
    }

    if(time - last_EEPROMHandler >= 1000) {
        last_EEPROMHandler = time;

        //  periodically update saved values
        EEPROM_setPrimaryColors(primaryR, primaryG, primaryB);
        EEPROM_setSecondaryColors(secondaryR, secondaryG, secondaryB);
        EEPROM_setSoundFontIndex(fontIndex);
        EEPROM_setBladeEffectIndex(bladeEffectIndex);
    }

    if(connectedToPhone) {
        if(time - last_WifiHandler >= 30) {
            last_WifiHandler = time;
            Wifi_handler();
        }
        if(time - last_WifiInfoHandler >= 1000) {
            last_WifiInfoHandler = time;
            Wifi_sendVoltage(batteryVoltage);
            Wifi_sendTemperature(IMU_getTemperature());
        }
    } else {
        //  try to connect to TCP client
        if(time - last_WifiHandler >= 1000) {
            last_WifiHandler = time;
            connectedToPhone = ESP_TryConnect();

        }
    }
}

volatile uint32_t lastStateChange = 0;
volatile uint8_t state = 0;
volatile uint32_t lastControlLoop = 0;
volatile uint32_t lastSwing = 0;
volatile uint32_t lastBtnUpdate = 0;

void controlLoop() {
    uint32_t time = millis();

    if(time - lastControlLoop < 5) return;
    lastControlLoop = time;
    uint32_t stateRuntime = time - lastStateChange;

    if(state == 0) {
        static bool startupTriggered = false;
        //  startup - must hold button for 1 second and release to finish startup and enter idle
        if(time > 1000) {
            Power_latchOn();
            if(!startupTriggered) Button_setBlink(100,100,100,100, 100, 100);
            startupTriggered = true;
            if(!Button_isPressed()) {   //  on button release, move to next state
                state = 1;
                Button_setPulse(50,50,50, 0, 20, 1000, 1000, 800, 700);
            }
        }
    } else if(state == 1) {
        //  idle - ready for button to start up
        static int8_t lastChargeMode = -1;

        if(time - lastBtnUpdate > 100) {
            lastBtnUpdate = time;

            uint8_t chargeMode = Power_isCharging();
            if(chargeMode != lastChargeMode) {
                lastChargeMode = chargeMode;

                if(chargeMode == NO_CHARGE) {
                    Button_setPulse(50,50,50, 0, 20, 1000, 1000, 800, 700);
                } else if(chargeMode == CHARGING) {
                    Button_setPulse(100,0,0, 0, 100, 500, 500, 400, 300);
                } else if(chargeMode == FULL_CHARGE) {
                    Button_setPulse(0,100,0, 0, 100, 1000, 1000, 800, 700);
                }
            }
        }

        if(Button_isPressed()) {
            state = 2;
            lastChargeMode = -1;
            lastStateChange = time;
        }
    } else if(state == 2) {
        //  button pressed in idle - check for blade on or power off
        if(stateRuntime > 3000) {    //  power off
            //  pressed long enough, show indicator for turn-off
            static bool powerOffTriggered = false;
            if(!powerOffTriggered) {
                powerOffTriggered = true;
                Button_setBlink(100,0,0,100, 100, 100);
            }
            if(!Button_isPressed()) {
                Power_latchOff();   //  kill on release
                state = 1;  //  if we get to this point, it means we are on USB power
            }
        } else {    //  blade on
            if(!Button_isPressed()) {
                //  button released, decide what to do
                lastStateChange = time;
                state = 10;
                // set blade effect/color
                if(bladeEffectIndex == 0) Neopixel_setSolid(primaryR, primaryG, primaryB);
                else if(bladeEffectIndex == 1) Neopixel_setUnstable(primaryR, primaryG, primaryB);
                else if(bladeEffectIndex == 2) Neopixel_setSpark(primaryR, primaryG, primaryB, secondaryR, secondaryG, secondaryB);
                else if(bladeEffectIndex == 3) Neopixel_setFlame(primaryR, primaryG, primaryB, secondaryR, secondaryG, secondaryB);
                else if(bladeEffectIndex == 4) Neopixel_setEnergetic(primaryR, primaryG, primaryB);
                else if(bladeEffectIndex == 5) Neopixel_setRainbow(0);
                else if(bladeEffectIndex == 6) Neopixel_setRainbowPulse();
                else if(bladeEffectIndex == 7) Neopixel_setRainbowStrobe();
                Neopixel_setExtend();
#ifndef NYANCAT
                if(fontIndex == 0) {
                    Audio_play(FONTID_A_EXTEND, 200, 0);
                } else if(fontIndex == 1) {
                    Audio_play(FONTID_B_EXTEND, 200, 0);
                }
#else
                Audio_play(FONTID_NYAN_HUM, 100, 1);
                Audio_stop(FONTID_NYAN_WAVE);
#endif
                Button_setBlink(primaryR*100/255, primaryG*100/255, primaryB*100/255, 100, 100, 100);
            }
        }

    } else if(state == 10) {
        //  blade extending

        //  TODO Start blade extension effect

#ifndef NYANCAT
        if(stateRuntime > 500 && (!Audio_isPlaying(FONTID_A_HUM)&&!Audio_isPlaying(FONTID_B_HUM))) {
            //  partially done with extension, start background hum
            if(fontIndex == 0) {
                Audio_play(FONTID_A_HUM, 150, 1);
                Audio_play(FONTID_A_SWING1H, 0, 1);
                Audio_play(FONTID_A_SWING1L, 0, 1);
                Audio_play(FONTID_A_SWING2H, 0, 1);
                Audio_play(FONTID_A_SWING2L, 0, 1);
            } else if(fontIndex == 1) {
                Audio_play(FONTID_B_HUM, 150, 1);
                Audio_play(FONTID_B_SWING1H, 0, 1);
                Audio_play(FONTID_B_SWING1L, 0, 1);
                Audio_play(FONTID_B_SWING2H, 0, 1);
                Audio_play(FONTID_B_SWING2L, 0, 1);
            }
        }
#else
#endif

        if(stateRuntime > 1000) {
            state = 11;
            lastStateChange = time;
        }

    } else if(state == 11) {
        //  blade idle

#ifndef NYANCAT
        // set blade effect/color
        if(bladeEffectIndex == 0) Neopixel_setSolid(primaryR, primaryG, primaryB);
        else if(bladeEffectIndex == 1) Neopixel_setUnstable(primaryR, primaryG, primaryB);
        else if(bladeEffectIndex == 2) Neopixel_setSpark(primaryR, primaryG, primaryB, secondaryR, secondaryG, secondaryB);
        else if(bladeEffectIndex == 3) Neopixel_setFlame(primaryR, primaryG, primaryB, secondaryR, secondaryG, secondaryB);
        else if(bladeEffectIndex == 4) Neopixel_setEnergetic(primaryR, primaryG, primaryB);
        else if(bladeEffectIndex == 5) Neopixel_setRainbow(0);
        else if(bladeEffectIndex == 6) Neopixel_setRainbowPulse();
        else if(bladeEffectIndex == 7) Neopixel_setRainbowStrobe();
#else
        if(stateRuntime >= 2350 && !Audio_isPlaying(FONTID_NYAN_WAVE)) {
            Audio_play(FONTID_NYAN_WAVE, 0, 1);
        }
        Neopixel_setRainbow(1);
#endif

        // set button effect/color
        if(time - lastBtnUpdate > 100) {
            lastBtnUpdate = time;
            if(bladeEffectIndex == 4 || bladeEffectIndex == 5 || bladeEffectIndex == 6) {
                Button_setSolid(100,100,100,100);
            }  else {
                Button_setSolid(primaryR*100/255, primaryG*100/255, primaryB*100/255, 100);
            }
        }

        //  ==============  SMOOTHSWING ===============
        rand(); //  just adds a bit more randomness to our collection
        int16_t humAudioVolume = 0;
        int16_t waveAudioVolume1 = 0;
        int16_t waveAudioVolume2 = 0;

#ifndef NYANCAT
        uint16_t maxVolumeSwingSpeed = 720;     //  dps
        uint16_t maxSwingVolume = 250;
        uint32_t swingActivateVelocity = 120;     //  dps
        uint32_t swingDeactivateVelocity = 60;     //  dps
        uint8_t transitionRegion1 = 45;    // degrees, must be < 180
        uint8_t transitionRegion2 = 150;    // degrees, must be < 180. Typically much larger than region1
        int16_t humVolume = 150;
        uint8_t minimumHumDuck = 25;    //  volume, out of 100
#else
        uint16_t maxVolumeSwingSpeed = 360;     //  dps
        uint16_t maxSwingVolume = 250;
        uint32_t swingActivateVelocity = 120;     //  dps
        uint32_t swingDeactivateVelocity = 60;     //  dps
        uint8_t transitionRegion1 = 45;    // degrees, must be < 180
        uint8_t transitionRegion2 = 150;    // degrees, must be < 180. Typically much larger than region1
        int16_t humVolume = 100;
        uint8_t minimumHumDuck = 25;    //  volume, out of 100
#endif

        // calculate swing strength
        uint32_t angularVelocity = IMU_getAngularVelocity();    // dps, scaled by 100
        uint32_t swingStrength;
        if(angularVelocity/100 > maxVolumeSwingSpeed) swingStrength = maxSwingVolume;
        else swingStrength =  angularVelocity * maxSwingVolume / 100 / maxVolumeSwingSpeed;     //  out of max swing volume
        swingStrength = sqrtInt(swingStrength*swingStrength*swingStrength)*maxSwingVolume / sqrtInt(maxSwingVolume*maxSwingVolume*maxSwingVolume);  // nonlinearity, basically to the power of 3/2

        static int8_t smoothswing_state = 0;
        static uint8_t waveAudioSelection = 0;
        static uint16_t transitionPoint1 = 0;    //  beginning of transition region 1
        static uint16_t transitionPoint2 = 0;    //  beginning of transition region 2
        static uint8_t loopingPair = 0;
        static uint32_t lastAccumulationTime = 0;
        static int accumulatedSwingAngle = 0;    //  degrees, scaled by 1000. Calculated with simple integration

        if(smoothswing_state == 0) {
            //  Not currently swinging

            humAudioVolume = humVolume;
            waveAudioVolume1 = 0;
            waveAudioVolume2 = 0;

            if(angularVelocity/100 >= swingActivateVelocity) {
                //  Swing started
                loopingPair = rand() % 2;
                waveAudioSelection = rand() % 2;

                uint8_t largestTransition = transitionRegion1 > transitionRegion2 ? transitionRegion1 : transitionRegion2;
                transitionPoint1 = rand() % (180 - largestTransition);
                transitionPoint2 = transitionPoint1 + 180;

                lastAccumulationTime = time;
                accumulatedSwingAngle = 0;

                smoothswing_state = 1;
            }
        } else {
            //  Currently swinging
            //  Accumulate swing angle
            accumulatedSwingAngle += angularVelocity * (time - lastAccumulationTime) / 2 / 100;
            accumulatedSwingAngle %= 360*1000;
            lastAccumulationTime = time;

            //  allow state to feed directly into the next state for a faster response
            if(smoothswing_state == 1) {
                //  Before transition region 1
                waveAudioVolume1 = waveAudioSelection ? 0 : 100;
                waveAudioVolume2 = waveAudioSelection ? 100 : 0;

                //  Check if in transition region 1 yet. Add an additional qualifier to account for when angle < 360 and right after transition 2
                if(accumulatedSwingAngle/1000 >= transitionPoint1 && accumulatedSwingAngle/1000 < transitionPoint2) {
                    smoothswing_state = 2;
                }
            }
            if(smoothswing_state == 2) {
                //  Transition Region 1
                int8_t fallingVolume = 100 - ( 100*(accumulatedSwingAngle/1000-transitionPoint1) / transitionRegion1 );
                int8_t risingVolume = 100*(accumulatedSwingAngle/1000-transitionPoint1) / transitionRegion1;

                waveAudioVolume1 = waveAudioSelection ? risingVolume : fallingVolume;
                waveAudioVolume2 = waveAudioSelection ? fallingVolume : risingVolume;

                if(accumulatedSwingAngle/1000 >= transitionPoint1 + transitionRegion1) {
                    smoothswing_state = 3;
                }
            }
            if(smoothswing_state == 3) {
                //  Between transition region 1 and 2
                waveAudioVolume1 = waveAudioSelection ? 100 : 0;
                waveAudioVolume2 = waveAudioSelection ? 0 : 100;

                //  Check if in transition region 2 yet
                if(accumulatedSwingAngle/1000 >= transitionPoint2) {
                    smoothswing_state = 4;
                }
            }
            if(smoothswing_state == 4) {
                //  Transition Region 2
                int8_t fallingVolume = 100 - ( 100*(accumulatedSwingAngle/1000-transitionPoint2) / transitionRegion2 );
                int8_t risingVolume = 100*(accumulatedSwingAngle/1000-transitionPoint2) / transitionRegion2;

                waveAudioVolume1 = waveAudioSelection ? fallingVolume : risingVolume;
                waveAudioVolume2 = waveAudioSelection ? risingVolume : fallingVolume;

                if(accumulatedSwingAngle/1000 >= transitionPoint2 + transitionRegion2) {
                    smoothswing_state = 1;
                }
            }

            //  modulate volume based on swing strength
            humAudioVolume = humVolume - swingStrength; if(humAudioVolume < minimumHumDuck) humAudioVolume = minimumHumDuck;
            waveAudioVolume1 = waveAudioVolume1 * swingStrength / 100;
            waveAudioVolume2 = waveAudioVolume2 * swingStrength / 100;

            //  check if still swinging
            if(angularVelocity/100 < swingDeactivateVelocity) {
                smoothswing_state = 0;
            }
        }

#ifndef NYANCAT
        if(fontIndex == 0) {
            Audio_setVolume(FONTID_A_HUM, humAudioVolume);
            Audio_setVolume(FONTID_A_SWING1H, loopingPair == 0 ? waveAudioVolume1 : 0);
            Audio_setVolume(FONTID_A_SWING1L, loopingPair == 0 ? waveAudioVolume2 : 0);
            Audio_setVolume(FONTID_A_SWING2H, loopingPair == 1 ? waveAudioVolume1 : 0);
            Audio_setVolume(FONTID_A_SWING2L, loopingPair == 1 ? waveAudioVolume2 : 0);
            Audio_setVolume(FONTID_B_HUM, humAudioVolume);
            Audio_setVolume(FONTID_B_SWING1H, loopingPair == 0 ? waveAudioVolume1 : 0);
            Audio_setVolume(FONTID_B_SWING1L, loopingPair == 0 ? waveAudioVolume2 : 0);
            Audio_setVolume(FONTID_B_SWING2H, loopingPair == 1 ? waveAudioVolume1 : 0);
            Audio_setVolume(FONTID_B_SWING2L, loopingPair == 1 ? waveAudioVolume2 : 0);
        } else if(fontIndex == 1) {
            Audio_setVolume(FONTID_B_HUM, humAudioVolume);
            Audio_setVolume(FONTID_B_SWING1H, loopingPair == 0 ? waveAudioVolume1 : 0);
            Audio_setVolume(FONTID_B_SWING1L, loopingPair == 0 ? waveAudioVolume2 : 0);
            Audio_setVolume(FONTID_B_SWING2H, loopingPair == 1 ? waveAudioVolume1 : 0);
            Audio_setVolume(FONTID_B_SWING2L, loopingPair == 1 ? waveAudioVolume2 : 0);
            Audio_setVolume(FONTID_A_HUM, humAudioVolume);
            Audio_setVolume(FONTID_A_SWING1H, loopingPair == 0 ? waveAudioVolume1 : 0);
            Audio_setVolume(FONTID_A_SWING1L, loopingPair == 0 ? waveAudioVolume2 : 0);
            Audio_setVolume(FONTID_A_SWING2H, loopingPair == 1 ? waveAudioVolume1 : 0);
            Audio_setVolume(FONTID_A_SWING2L, loopingPair == 1 ? waveAudioVolume2 : 0);
        }
#else
        int volume = 0;
        if(angularVelocity > 36000) volume = 200;
        else if(angularVelocity > 18000) volume = 100;
        Audio_setVolume(FONTID_NYAN_WAVE, volume + 30);
#endif

        if(Button_isPressed()) {
            state = 12;
            lastStateChange = time;
        }

    } else if(state == 12) {
        //  button pressed in blade mode
        if(!Button_isPressed()) {
            //  blade retracting
            Neopixel_setRetract();
            state = 19;
            lastStateChange = time;
#ifndef NYANCAT
            if(fontIndex == 0) {
                Audio_play(FONTID_A_RETRACT, 200, 0);
            } else if(fontIndex == 1){
                Audio_play(FONTID_B_RETRACT, 200, 0);
            }
#else
#endif
            Button_setBlink(primaryR*100/255, primaryG*100/255, primaryB*100/255, 100, 100, 100);
        }
    } else if(state == 19) {
        //  blade retract
        if(stateRuntime > 300) {
#ifndef NYANCAT
            Audio_stop(FONTID_A_HUM);
            Audio_stop(FONTID_A_SWING1H);
            Audio_stop(FONTID_A_SWING1L);
            Audio_stop(FONTID_A_SWING2H);
            Audio_stop(FONTID_A_SWING2L);
            Audio_stop(FONTID_B_HUM);
            Audio_stop(FONTID_B_SWING1H);
            Audio_stop(FONTID_B_SWING1L);
            Audio_stop(FONTID_B_SWING2H);
            Audio_stop(FONTID_B_SWING2L);
#else
            Audio_stop(FONTID_NYAN_HUM);
            Audio_stop(FONTID_NYAN_WAVE);
#endif
        }
        if(stateRuntime > 800) {
            state = 1;
            lastStateChange = time;
            Button_setPulse(50,50,50, 0, 20, 1000, 1000, 800, 700);
        }
    }
}

int main(void) {
    PLL_Init(Bus80MHz);

    setupInterrupts();

    setupPins();

    Power_initialize();
    IMU_initialize();
    Neopixel_initialize();
    Audio_initialize();
    Wifi_initialize();
    EEPROM_initialize();
    Button_initialize();

    while(millis() < 300) {}      //  we need a delay so that the ESP-01 can power up!
    ESP_Init();
    fontIndex = 1;
    connectedToPhone = false;

    Button_setSolid(100,0,0,100);
//    Neopixel_setRainbow(false);
//    Neopixel_setExtend();
//    uint32_t pr = millis();
//    uint8_t done = 0;
    while(1) {
        handlerLoop();
//        Neopixel_handler();
//        if (millis() - pr > 4000 && !done) {
//            Neopixel_setRetract();
//            done = 1;
//        }
        controlLoop();
    }
}

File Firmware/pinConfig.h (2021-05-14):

#ifndef PINCONFIG_H_
#define PINCONFIG_H_

#include <stdint.h>
#include <stdbool.h>
#include "inc/hw_types.h"
#include "inc/hw_memmap.h"
#include "driverlib/sysctl.h"
#include "driverlib/gpio.h"

// ***** Power *****

#define PowerON_b GPIO_PORTA_BASE
#define PowerON_p GPIO_PIN_0

#define Vsense_b GPIO_PORTE_BASE
#define Vsense_p GPIO_PIN_1

#define Button_Sense_b GPIO_PORTE_BASE
#define Button_Sense_p GPIO_PIN_0

#define Charge_Bias_b GPIO_PORTD_BASE
#define Charge_Bias_p GPIO_PIN_7

#define Not_Charging_b GPIO_PORTC_BASE
#define Not_Charging_p GPIO_PIN_7

// *****************

// ****** ESP ******

//#define ESP_IO0_b GPIO_PORTE_BASE
#define ESP_IO0_b GPIO_PORTA_BASE
#define ESP_IO0_p GPIO_PIN_1

#define ESP_IO2_b GPIO_PORTF_BASE
#define ESP_IO2_p GPIO_PIN_2

#define ESP_RX_b GPIO_PORTC_BASE
#define ESP_RX_p GPIO_PIN_5

#define ESP_TX_b GPIO_PORTC_BASE
#define ESP_TX_p GPIO_PIN_4

#define ESP_EN_b GPIO_PORTF_BASE
#define ESP_EN_p GPIO_PIN_3

#define ESP_RST_b GPIO_PORTC_BASE
#define ESP_RST_p GPIO_PIN_6

// *****************

// ****** SPI ******

#define CS_SD_b GPIO_PORTA_BASE
#define CS_SD_p GPIO_PIN_3

#define CS_DAC_b GPIO_PORTE_BASE
#define CS_DAC_p GPIO_PIN_4

#define MISO_b GPIO_PORTA_BASE
#define MISO_p GPIO_PIN_4

#define MOSI_b GPIO_PORTA_BASE
#define MOSI_p GPIO_PIN_5

#define SCK_b GPIO_PORTA_BASE
#define SCK_p GPIO_PIN_2

// *****************

// ****** I2C ******

#define SCL_b GPIO_PORTA_BASE
#define SCL_p GPIO_PIN_6

#define SDA_b GPIO_PORTA_BASE
#define SDA_p GPIO_PIN_7

// *****************
// ****** LED ******

#define Neopixel_b GPIO_PORTF_BASE
#define Neopixel_p GPIO_PIN_1

#define LED_R_b GPIO_PORTD_BASE // PWM 6, Module 0 Generator 3
#define LED_R_p GPIO_PIN_0

#define LED_G_b GPIO_PORTE_BASE // PWM 5, Module 0 Generator 2
#define LED_G_p GPIO_PIN_5

#define LED_Anode_b GPIO_PORTB_BASE // PWM 3, Module 0 Generator 1
#define LED_Anode_p GPIO_PIN_5

// *****************

#endif /* PINCONFIG_H_ */

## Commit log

2020-10-24 Made hilt-side pcb
    [Blade PCB.PrjPCB, Blade-Side PCB.PcbDoc, Blade-Side Schematic.SchDoc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]
2020-12-24 Schematic Finished, ready for review
    [ESP-01.PcbLib, ESP-01.SchLib, Hilt-Side Schematic.SchDoc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]
2020-12-27 doing pcb layout
    [Lightsaber PCB Library.PcbLib, Lightsaber Schematic Library.SchLib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]
2020-12-27 finished layout + routing, ready for review
    [Main PCB.PcbDoc, Microcontroller.SchDoc, Power.SchDoc]
2020-12-27 finished blade side connector, panelizing
    [Blade PCB.PrjPCB, Blade-Side PCB.PcbDoc, Blade-Side Schematic.SchDoc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]
2020-12-28 panelized, ready for gerber review
    [Blade-Side PCB.PcbDoc, Hilt-Side PCB.PcbDoc, Main PCB.PcbDoc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]
2020-12-30 sent to manufacturer
    [Blade-Side PCB.PcbDoc, Hilt-Side PCB.PcbDoc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]
2021-01-12 RGB Button Function
    [Main PCB.PrjPCB, Peripherals.SchDoc, jlcpcb.PcbDoc]
2021-01-12 add button LED library functions - solid, blink, pulse
2021-01-16 Add ADC functions
    Functions for init ADC, check battery voltage and check if button is pressed
2021-02-04 Neopixel and power code
    [Microcontroller.SchDoc]
2021-04-12 add gyroscope code
    [Microcontroller.SchDoc]
2021-05-14 pull from original 445L repository
    [BOM.xlsx, Microcontroller.SchDoc]
